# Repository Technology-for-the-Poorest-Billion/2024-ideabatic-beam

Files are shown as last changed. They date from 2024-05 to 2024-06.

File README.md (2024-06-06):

# SMILE, by Ideabatic
This is an IIA project, carried out in Easter term with the intention to improve upon the design of the current SMILE prototype.

# To Navigate Through this Repository

- The design considerations are linked coherently in a logic order, starting with a [formalisation of the design problem](https://github.com/Technology-for-the-Poorest-Billion/2024-ideabatic-beam/blob/main/Benjamin_Outputs/Our_Design_Problem_and_Context.md).

- The key information for mechanical design and prototyping can be found [here](https://github.com/Technology-for-the-Poorest-Billion/2024-ideabatic-beam/tree/main/mechanical%20design)

- The key information for electronic design and prototyping can be found [here](

## Setup (electronics)
In the final prototype, [the items listed here were used.](https://github.com/Technology-for-the-Poorest-Billion/2024-ideabatic-beam/blob/main/BillOfMaterials.md)

### Connections
The pi should be connected as [described here.](https://github.com/Technology-for-the-Poorest-Billion/2024-ideabatic-beam/blob/main/ElectricalConnections.md)
The connections can be switched around as long as they are appropriately changed in the code. The sensors initiate the pins in their own pieces of code, whereas the button, switch, and buzzer are initialised in main.py.

### Pi Setup
1. Install micropython onto the board. 
  - This can be done via thonny; connect the Pi to the computer whilst holding the BOOTSEL button, and install the standard relevant micropython.
2. Install the ssd1306 and dht libraries.
  - This can be also be done via thonny; with the pi connected and responding, click tools -> manage packages and install the libraries there.
3. Port over all items in the code folder.
4. The Pico, on boot, will run main.py by default. For testing, mainTest.py is recommended, as this changes the polling rate to 1 per second, and artificially inflates the heat loss so that the display stages can be shown. This also allows for testing of the buzzer.

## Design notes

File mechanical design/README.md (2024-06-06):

Author: Ness

### Handover notes

#### Prototyping insights
1. CAD design medium
2. 3D printing

#### Main design considerations
1. Snap-fit connection between module and door
2. Compatible joints between module base and lid
3. Drop resistance of electronics module
4. Dimensioning to fit components

#### Material selection (further discussed in Benjamin's part)

### CAD

#### Solidworks files
1. Door top 2024.SLDPRT [Part file with door top final design and suppressed 3D printed prototype iterations]
2. Module casing base 2024.SLDPRT [Part file with module casing base final design]
3. Module casing top 2024.SLDPRT [Part file with module casing lid final design]

#### OpenSCAD code [not used in final design]
1. door top modification.scad [OpenSCAD code of preliminary modifications to the door]
2. module casing.scad [OpenSCAD code of preliminary module casing design]
3. shell.scad [OpenSCAD code of assembled shell .STL components]

#### Other drawings
1. SMILE - shell only.STL [.STL export of the shell]

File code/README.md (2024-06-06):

### This folder contains the relevant code required to run the Pi. [For setup instructions, click here.](https://github.com/Technology-for-the-Poorest-Billion/2024-ideabatic-beam/tree/main)
# Logic Process:
1. The code imports all the functions, does so by importing the respective files. When importing test.py, the tests are carried out. If there is an issue, the terminal will let you know where the failure was. Switch/button failure is difficult to detect and so will have to be done in use. Buzzer testing can also be done but can be annoying if tested each time the code is ran.
2. Initialises all the extra electronics: the switch/button/buzzer so that it is ready to be used. Also imports the dictionary in constants.json with all the relevant values stored there.
3. Waits for the button to be pressed before starting the main loop. This is done by raising an interrupt on the rising edge of a button push (active low).
4. Once this is done, the push button is changed to the class SoftSwitch, which allows for debouncing and detection of double clicks, which on first click will revert the time remaining to the last measured time before boot up. Any further clicks will reset the cool life completely.
5. Now, the main loop of the code runs in a try: section. This ensures that if there are any errors that prevent the running of the code, the constants are dumped back to the JSON (important to remember the last known Q for later reversion), and the display is safely turned back off. 
6. The heat life calculations run first, where the heat loss rate is calculate using the temperature difference between the core and outside (T_outside - 0) and the (constant) thermal resistance of the cooler box. An estimation of the remaining cool life is made based on the assumption that the temperature remains constant, though this is updated every loop (of time period tdelta, default 5 minutes). If the remaining cool life is negative, the code will cause the buzzer to buzz for 2 seconds.
7. The remaining cool life is then displayed and the door switch is checked. If the door has been open for two consecutive checks, the switch will buzz every 5 minutes until it is shut. Note that the buzzer sound is irritating at worst.
9. The code then sleeps for tdelta, default 5 minutes before running the main loop again until power is cut.

# Issues and further improvements
- The battery life of the module can certainly be improved. When sleeping, the module sips 30mA at 3V which depletes 2 AA batteries in 78 hours, whilst the expected cool life at 22 degrees is just over 100 hours. 
  - The pico's power draw can be reduced by using machine.lightsleep instead of sleep, and additionally reducing the power draw of the display (i.e. by using a lower display brightness, using the display with a duty cycle).
    - Note that lightsleep may cut power to the display, and can have problems with the external modules. It is also incredibly annoying to prototype with, requiring a manual reconnect of the usb connector after each use.
    - If this is used, it may be beneficial to have the display only run when the button is pressed via an interrupt; this takes advantage of this aspect to further reduce the power consumption
- A relatively easy improvement to the code would be to have the display turn on for a second when the button is pressed once, before shutting off again, though this will make the module less useful; this was considered but decided against.
- A smaller on circuit temperature sensing component can be used (i.e. a TMP36) instead of the bulky DHT22 module currently used to improve the power draw, and allowing for more flexibility instead of relying on a library.
- The overall size of the module can be reduced by sourcing more use case specific components.
- A rechargeable battery can be used to provide the required lifetime, though this would require a battery management system too, along with a USB port which could reduce water resistance.
- A different microcontroller with even lower power draw may be preferable, possibly an ESP32, which has the added benefit of being very small.

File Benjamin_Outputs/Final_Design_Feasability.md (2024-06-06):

## Validating Analysis of the Final Design across all dimensions

### Modularity: 
- entirely electronically and mechanically modular for easy charging and opt-in 

### Robustness: 
- With the existing sealing not being compromised, water resistance remains
- With the [mechanical solutions implemented](https://github.com/Technology-for-the-Poorest-Billion/2024-ideabatic-beam/blob/main/mechanical%20design/handover%20notes/drop%20resistance.md), the final product is drop resistant

### Temeprature Prediction Veracity: 
- 1º overestimate proven to be sufficiently accurate



### Cost effectiveness: Validating Analysis
- Take the [worst-case quantity discounting for electronic components](https://github.com/Technology-for-the-Poorest-Billion/2024-ideabatic-beam/blob/main/Benjamin_Outputs/Initial_Design_Candidates.md)
- Add the single-unit cost of all materials used for housing, assuming no quantity discounting

Material costs:
- 0.9mm thick x 9080mm2 for [aluminium sheet](https://www.metals4u.co.uk/materials/aluminium/aluminium-sheet/aluminium-mill-finish-aluminium-sheet/3123-p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) for top of module casing
£0.22 for 0.01m2
- 30x14 of [2mm thick acrylic](https://www.perspexsheet.uk/clear-000-perspex/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) for screen display on top of module case: £0.02 per unit
- 13226.4mm3 of [ABS](https://www.plasticsdirect.co.uk/products/abs-sheet-acrylonitrile-butadiene-styrene), costs £1.37/kg; density is 1 g/cm3, so we are using 13.2264g, so material cost is £0.02; if we want it pre-processed, £0.31.
- two [PVC button covers](
https://undercontrol.co.uk/accessories/switches/pvc-splash-resistant-rocker-switch-cover/), £0.24 each

So only adds £1.03 to material costs.

<br />

Detailed research, including further input from the project partner to quantify the additional manufacturing costs is necessary for a complete analysis, but the original £15 in the [problem definition](https://github.com/Technology-for-the-Poorest-Billion/2024-ideabatic-beam/blob/main/Benjamin_Outputs/Our_Design_Problem_and_Context.md) was not expected to include manufacturing.

<br />

Hence, the final prototype is costed at £12.02 (electronics) + £1.03 = £13.05 in the worst case. So we remain under budget!

### Insulation: Validating Analysis

*This uses a different model: split the total thermal resistance of ABS into two parts: the insulation in door face and the insulation in all other faces. Then the thermal resistance in door face is reduced by a factor of (62-7)/55, which represents the percentage decrease in thickness; conservatively assuming that air in parallel with insulating material is as bad as just air in the top 7mm of the door*



Plugging the value for the total thermal resistance of the device into the cool life prediction algorithm, 



It is shown that the new device maintains 96% of the original cool lifetime, scoring an 8.98 on the insulation dimension according to its dimension characteristic.

<br />

### Conclusion

All five key dimension requirements are satisfied; a new KPI can be computed based on the slightly reduced insulation, at KPI/1000 = 27. Hence this still remains the best design candidate, and is proven to be a working prototype design. 

The next step is to build the actual product out of the recommended materials.

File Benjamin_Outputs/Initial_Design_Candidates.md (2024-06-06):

# The candidate designs

Based on previous work informing a ['default design'](https://github.com/Technology-for-the-Poorest-Billion/2024-ideabatic-beam/blob/main/Benjamin_Outputs/Our_Design_Problem_and_Context.md), four general candidate designs following this archetype were brainstormed, along with one outside of the archetype (Candidate 5):

IMG_548055A1CA77-1

<br />
<br />

Applying the [conservative principles for analysis](https://github.com/Technology-for-the-Poorest-Billion/2024-ideabatic-beam/blob/main/Benjamin_Outputs/Conservative_Analysis_Principles.md), each design was analysed via *eliminating analysis*, to result in a quantified measure of its best-case performance. Best-case performance was analysed at this stage to ensure that no viable designs were discarded. 

<br />

## Candidate 1: Direct Axial Connection - Eliminating Analysis on the Insulation Dimension



<br />
<br />

- This is the design prototyped by last year's group
- They neglected the obvious risk of insulation compromise

The first dimension on which Candidate 1 will be scored is insulation, in an attempt to elimiinate it early on the grounds that it compromises insulation to an unacceptable level. 

### The Problem:
- Electrical wiring, made of copper, is very thermally conductive, so an axial path of heat flow is effectively short-circuited.
- Additionally, there is a manufturing and design interdependence. Given that the door is intended to be manufactured by polymer casting, there is significant tolerance. 
- To ensure that the wires fit in the door, the design therefore needs to made too wide. Then with the tolerance, the best case still results in some parts in the manufacturing batch containing a significant air gap around the wires. 

Inkeeping with the conservative analysis principles, the analysis will be done with the following assumptions, each of which leads to the most conservative estimate of insulation compromise:
- the wiring used is has the lowest readily available diameter, 1 mm
- manufacturing is done with maximal precision. For casting a polymer, this is of order ±1 mm accuracy on casting

- the change in area of the door cross-section is neglected

### Optimising Geometry: 
Coordinate geometry reveals that the optimal housing for wiring is 'figure 8' shaped.
Evaluating the area of the lens shape created by the two tunnels overlapping, this results in: 1.57mm<sup>2</sup> wiring, 3.83mm<sup>2</sup> air.

IMG_BBFAF02D5158-1

The bulk of the door is made of the insulating material tricast. 
Previous contributors computed the average thermal resistance *per unit depth* of door to be 

$\ {R_{th, tri}} =$ = 198.6 KW<sup>-1</sup>m<sup>-1</sup>

The area of copper in two 1mm diameter copper wires is 1.57 mm<sup>2</sup>, 

$\implies$ *per unit depth*,

$\ {R_{th, copper}} =\frac{1}{\lambda\times{A}} =\frac{1}{{398}\times{1.57\times{10^-6}}} =$ 1600 KW<sup>-1</sup>m<sup>-1</sup>

$\ {R_{th, air}} =\frac{1}{\lambda\times{A}} =\frac{1}{{0.025}\times{3.83\times{10^-6}}} =$ 10.4 x 10<sup>6</sup> KW<sup>-1</sup>m<sup>-1</sup>

The three resistive elements are in parallel through the entire depth of the door, so 

*modelling these as a thermal resistances in parallel with the insulating material tricast*,

$\frac{1}{R_{th, total}} = \frac{1}{R_{th, copper}} + \frac{1}{R_{th, air}} + \frac{1}{R_{th, tri}}$

$\implies {R_{th, total}} =$ 176.7 KW<sup>-1</sup>m<sup>-1</sup>

Thus the thermal insulation of the door per-unit depth is reduced by 11.04%. 

Using data from previous contributors to compute the new total thermal resistance between the ice pack at the centre of the cooling device and the external air, the thermal resistance is found to be reduced from 9.72 to 8.88 KW<sup>-1

The new value for overall thermal reistance was simulated in the cool life estimation algorithm, and the effect of the axial connection was plotted:



Cool life decreases from 97.5 hours to 89.1 hours in 24ºC ambient temperature. 

This is deemed feasible - the reduction in cool lifetime is not drastic enough to eliminate this candidate entirely. 

However, it will be scored lower than the other design candidates, which don't threaten any significant reduction in insulation. 

According to the scoring characteristic, this design therefore receives a score of 7.6 on the insulation dimension. 

## Candidate 2: Wireless Communication - Eliminating Analysis on the Cost Effectiveness Dimensions

The dimension on which this design is most liekly to be unfeasible is cost effectiveness. 

According to conservative analysis principles, the best-case possibility is explored: 
- the lowest-cost implementation is used, which is to use a second microcontroller which can wirelessly communicate with the Pi Pico
- the quantity discounts for bulk-ordering is assumed to follow the best-case exponential decay per-unit cost curve derived below

### The electrical components needed

- Pi Pico → Pi Pico W to allow for wireless communication

- Wireless module microcontroller (ESP8266) to operate temeprature sensor and communicate with Pi Pico

- AA batteries x2 needed to power ESP8266

- Holder for AA batteries

### Deriving Possible Quantity Discount Curves
- Most electrical component websites offered limited information on the discounts offered for ordering components in large quantites:



#### Table 1: Example of publicly avaialble quantity discounting data

- Via private communication with suppliers about buk orders, a more detailed range of possible quantity discounting curves were obtained.
- The discounting data received only extends to 1000 units at most, whereas our batch size was 3000
- By modelling the quantity discounts a logarithmic decay, the range of cost curves were extrapolated to a batch size of 3000 to obtain a best-case and worst-case estimate for the quantity discount offered on electrical components. 
 




- For a best-case eliminating analysis, the most generous discounting rate across websites and components was assumed 

****Best-case Per-unit price for 3000 units = 0.5 x Per-unit price for 1 unit****

This is the best-case estimate which is used for the cost-effectiveness feasability assessment of Design Candidate 2. 

### Best-case cost effectiveness of Candidate 2

| Part Description | Single Unit Cost | Per-Unit Cost in batch of 3000 | 
|-|-|-|
|Raspberry Pi Pico W| £5.80 | £2.90 | 
|ESP8266| £4.22 | £2.11 | 
|DHT22| £4.74 | £2.37 | 
| OLED Display | £10.19 | £5.10 | 
| Door-sensing switch | £1.02 | £0.51 |
|Buzzer for door open alert| £2.15 | £1.08 | 
|Battery holder x2 | £1.96 | £0.98 | 
|AA Batteries x4 | £2.316 | £1.16 | 

The cost of electrical wiring, resistors and capacitors is neglected. 

#### Best-case per-unit cost for 3000 units: £16.20

This is above the budget (even before considering the cost of the housing for the module), making the cost effectiveness score zero, giving Candidate 2 a KPI of zero. 

Candidate 2 will therefore be eliminated from consideration without further consideration. 

The other design candidates' electronic components are costed at £24.03 for a single unit, which is a per-unit cost of £14.42 in the worst-case quantity discount, and £12.02 in the best case, thus they are all within budget and receive score of 5. 

<br />

## Scoring all candidates on all dimension

Scoring each design on according to the [scoring criteria](https://github.com/Technology-for-the-Poorest-Billion/2024-ideabatic-beam/blob/main/Benjamin_Outputs/Design_Approach.md), the following table was constructed, representing the overall performance. Candidate 2 was not scored as it was proven inviable on the insulation dimension. 

<br />

| Dimension | Candidate 1 Score | Candidate 2 Score | Candidate 3 Score | Candidate 4 Score | Candidate 5 Score | 
|-|-|-|-|-|-|
| Cost effectiveness | 5 | 0 | 5 | 5 |5 | 
| Robustness | 5 | - | 8 | 8 |10 | 
| Insulation | 7.6 | - | 10 | 10 |10 | 
| Temp Prediction Veracity | 10 | - | 10 | 10 |6 | 
| Modularity | 6 | - | 6 | 6 |10 | 
| **Overall KPI /1000** | **11.4** | - | **24** | **24** | **30** |

<br />







Hence, the design taken forward is candidate 5, with a specific focus on improving/validating its performance in the 'temperature prediction veracity' dimension, and ensuring that its cost effectiveness, robustness, insulation and modularity are upheld, as it is selected for its good performance across these dimensions. 

<br />
<br />

The specifics of how this design could be implemented, particularly its [door sensing mechanism](https://github.com/Technology-for-the-Poorest-Billion/2024-ideabatic-beam/blob/main/Benjamin_Outputs/Module_Placement.md) and the placement of the [temperature sensor](https://github.com/Technology-for-the-Poorest-Billion/2024-ideabatic-beam/blob/main/Benjamin_Outputs/Internal_DHT_Analysis.md) were then analysed.

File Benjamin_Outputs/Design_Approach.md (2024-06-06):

# Communicating Design Decisions

Part of this project's useful output is a thorough documentation and justification of all design decisions made, quantified and visualised where possible. 

This is useful in the immediate term, as a means of presenting and justifying design decisions to the project partner, and also in the future, as subsequent work on this design problem will be streamlined by the clarity of this discussion, illustrating possibilities that have already been explored and eliminated. 

<br />

The [formalised problem definition](https://github.com/Technology-for-the-Poorest-Billion/2024-ideabatic-beam/blob/main/Benjamin_Outputs/Our_Design_Problem_and_Context.md) naturally gives rise to five key dimensions:
- Cost effectiveness
- Robustness: Environmental resistance and mechanical robustness
- Insulation
- Veracity of temperature prediction
- User friendliness, primarily concerned with modularity

<br />

Each possible design (known hereon as a design candidate) should perform well in all five dimensions. 

It will be scored against each dimension, using the scoring criteria outlined below.

<br />

# Scoring Candidates on Each Dimension

## Scoring Criteria

Based on personal judgement and continual discussion with the project partner, the following subjective (yet defensible) criteria were used for scoring on the five dimensions. 

These criteria can be thought of as a way of taking the physical performance dimension (eg cool lifetime) and mapping it to performance in a dimension (eg insulation). 

### Cost effectiveness
- Any design which is unfeasible within the £15 budget is scored zero
- The remaining four designs are inseparable on cost (neglecting cost of wiring), so are all scored 5
- This is a rudimentary scoring characteristic, but given that we only have two possibilities for costing (given that four of our designs have exactly the same cost), it is sufficient

### Robustness: Environmental resistance and mechanical robustness
The primary risks for environmental and mechanical degradation are water ingress and damage to external wiring.
- Any design which might be susceptible to water ingress is scored 5
- Any design which requires external wiring is scored 8 (can be mitigated by further printing wiring)
- Any design with both of the above is scored 4
- Any design with neither is scored 10

### Insulation
- Any design which does not compromise insulation is scored 10
- Any design which multiplies the 24º cool lifetime by a factor k is scored k<sup>3</sup> x 10
- The cubic scoring characteristic gives severe weighting to the cool lifetime of the final product, which is appropariate since improving cool lifetime is the SMILE's core function

### Veracity of temperature prediction
- Any design with the temperature sensor outside the insulation is scored 9 (an extra layer between sensor and vaccines increases error in algorithm, as there is uncertainty associated with the exact thermal resistance of each layer)
- Any design with the temperature sensor susceptible to mild inorganic heating (eg due to contact with the electronics) by less than 1ºC is scored 7
- Any design with both of the above is scored 6
- Other designs are scored 10
- Only small scoring penalties are applied here as underestimates of the cool lifetime are not costly - whereas overestimating cool lifetimes could cost lives!

### User friendliness, primarily concerned with modularity
- Any design which has both mechanical and electrical modularity is scored 10
- Any design which is mechanically but not electrically modular is scored 6
- This is based on the preferences of the project partner in designing two versions of the product with one manufacturing process, so that users can easily opt in or out of the electronic version

<br />

Once scored against each dimension, a design candidate's performance can be visualised using a radar plot.



****Figure 1: Example of a radar plot****

The scores will then be combined to give a Key Performance Indicator (KPI), which quantifies the overall performance potential of a design. 

Given that a failure to be fit for purpose in any of the five dimensions would render a design unsuitable, the KPI is calculated as the product of the five scores.

$\{KPI}$ = Score 1 $\times$ Score 2 $\times$ Score 3 $\times$ Score 4 $\times$ Score 5

This product-rating method is also useful for eliminating design candidates: evidence that a candidate is unsuitable on any of the five dimensions immediately sets its KPI to zero and eliminates it from the design process. 

As such, each candidate is checked first against its most problematic dimension in a 'feasability test', so that it can be quickly eliminated if unfeasible. 

The radar plot conveniently visualises three important things:
- Area shows which design candidates to proceed with
- Relative strengths and weaknesses of each design candidate
- Areas for maximum improvement on each design candidate

[This document](https://github.com/Technology-for-the-Poorest-Billion/2024-ideabatic-beam/blob/main/Benjamin_Outputs/Initial_Design_Candidates.md) shows the general candidate designs which resulted from brainstorming, and the feasability assessments and dimension scoring which resulted in the prototyped design being taken forward.

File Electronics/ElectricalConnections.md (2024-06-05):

# Electrical connections to Pi Pico
Note that the below makes reference to the board pins and GPIO pins. See pico.pinout.xyz for more information.

## Pinout:
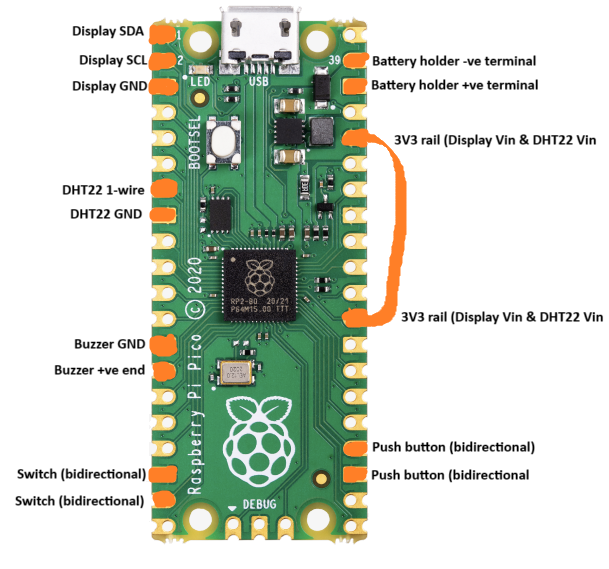
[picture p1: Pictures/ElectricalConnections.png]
Electrical Connections


|Board|GPIO/V|Purpose|
|-|-|-|
|1|GP0|Display SDA|
|2|GP1|Display SCL|
|3|GND|Display GND |
|7|GP5|DHT22 1 wire |
|8|GND|DHT22 GND|
|13|GND|Buzzer GND|
|14|GP10|Buzzer Positive end|
|18|GND|Switch (bidirectional)|
|19|GP14|Switch (bidirectional)|
|23|GND|Push button (bidirectional)|
|24|GP18|Push button (bidirectional)|
|29|GP22|Connected to board 36(3V3 Out). Used as an extended positive terminal for further wires. (Display Vin and DHT Vin are connected to this)|
|36|3V3 Out|Connected to board 29 (GP22). Used as an extended positive terminal for further wires. (Display Vin and DHT22 Vin are connected to this)|
|38|GND|Battery holder positive terminal|
|39|VSYS|Battery holder positive terminal|

<!--
<BR>Board 1 (GP0): Display SDA
<br>Board 2 (GP1): Display SCL
<br>Board 3 (GND): Display GND 
<br>Board 7 (GP5): DHT22 1 wire 
<br>Board 8 (GND): DHT22 GND
<br>Board 13 (GND): Buzzer GND
<br>Board 14 (GP10): Buzzer Positive end
<br>Board 18 (GND): Switch (bidirectional)
<br>Board 19 (GP14): Switch (bidirectional)
<br>Board 23 (GND): Push button (bidirectional)
<br>Board 24 (GP18): Push button (bidirectional)
<br>Board 29 (GP22): Connected to 3V3. Used as an extended positive terminal for further wires. (Display Vin and DHT Vin are connected to this)
<br>Board 36 (3V3 Out): Connected to board 29 (GP22). Used as an extended positive terminal for further wires. (Display Vin and DHT22 Vin are connected to this)
<br>Board 38 (GND): Battery holder positive terminal
<br>Board 39 (VSYS): Battery holder positive terminal -->

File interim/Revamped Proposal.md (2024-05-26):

# Problem description

<!-- Brief overview of the problem, context and engineering approach to tackle the problem.-->

Current vaccine carriers use cooler boxes which are poorly adapted to the conditions that they are expected to tackle, often with very poor cooling lifetimes that can mean vaccines spoil before they reaches their destination. These were shown to last approximately 4 hours in field conditions, which is simply not enough for journeys that can often last 2 days in over 25ºC heat. Human error is also a large problem, as healthcare workers may unknowingly leave cooler boxes open for long periods of time, significantly reducing the cooling lifetime. There is also an issue in which, despite requiring four standard ice packs placed appropriately, workers may end up only using one or two, placed haphazardly. 

SMILE, by Ideabatic, aims to combat this issue with a uniquely designed cooler box containing only a single ice pack that can keep 18 vaccines cool for up to 4 days (120 hours), along with a self-closing door mechanism to reduce human error. The design also incorporates a waterproof casing with further insulation and straps for comfortable carry as a backpack. Clearly responding to a genuine need, the impact of SMILE can be assessed against UN's sustainable development goals, most obviously Goal 3: Good Health and Wellbeing. 

<!-- Contextualising the project, embracing last years work and being explicit about improvements we intend ot make-->

Ideabatic has been collaborating with many different project groups to develop a temperature display electronics module as an add-on product to the SMILE device. The need for such a product was identified after some users relayed that they wanted to keep track of the temperature in the SMILE device to better ensure the vaccine is stored properly.

Previous project groups have worked on different electronics housing and door slot designs, developing temperature and cool life prediction algorithms and door alert systems, and improving other mechanical features such as the self-closing mechanism and lid ergonomics. This project aims to build upon the work done by these previous groups, identifying the limitations of previous designs and improving on these features based on feedback given by Kitty Liao (founder of SMILE) and personal insight.

# Assessment of the quality of the proposal

<!--Evaluate its value in the context of the project. What will it solve, is it safe, etc. Check Lara’s slides for what to cover.-->

The SMILE coolbox works as it is, and is safe for users. Despite this, it has come up against approval and funding issues. Ideabatic has decided to take the device to developed markets (such as the UK) as a proof of concept, along with the addition of further features which can be included or removed as costs require for developing market applications. 

There are three core improvements to the existing design that we are looking to implement:

The door being self-closing, and/or warning users if left open, has been proven by field tests to be a functional necessity. Due to carelessness, the door is often left open, which leads to unnecessary spoiling of the vaccines. Ergonomics of the door opeartion is essential for ease of use, and must accommodate the varied nature of applications and shapes and sizes of users. 

Implementing a simple display, showing the cool life remaining, or at its simplest, an 'OK' or 'NOT OK' signal, is a high-impact safety feature, which allows the administer of vaccines to be aware when vaccines have spoiled, and when they need to return to restock the icepack. Here, information saves lives. 

The current algorithm for estimating the temperature in each vaccine compartment has been calibrated assuming that the SMILE door is closed at all times. In reality, the door will frequently be opened, especically during an administration session. This leads to much faster cooling rates (extent to be determined), and thus shorter cool lifetimes. To obtain an accurate temperature estimate and make the display worthwhile, the algorithm should thus be improved to include the effect of the open door; preferably coupled with a real-time sensor on the door to indicate its state. 

# Presentation of the proposal

<!--Technical aspects may be described here--> 

## Electronics
The main electronic priority is to implementing a functioning, modular and accurate temperature sensing display. The team last year did this through an Arduino, though our group is looking to use a Raspberry Pi Pico. The hope is to have a user-friendly interface that will display whether the vaccines are within the safe temperature range and, upon further interaction, how many hours the vaccines stored inside will likely last under the current temperature conditions. There is also the possibility of adding a GPS sensor to locate the cooler and then log this, along with the temperature sensing data, in a storage device that can later be accessed. This should all be incorporated in a module which can be removed and fit as desired, leading to some intricacies within the actual door design. This module will contain a temperature sensor, measuring the ambient temperature, and there will also be a static temperature sensor embedded inside the door. The module will then be able to interact with this sensor when attached to the door. 

Another priority, albeit lower, is the improvement of the temperature sensing algorithm. The current function works by calculating the heat energy lost to the surroundings (treating the thermal resistance and total ice pack energy as constants) and decrementing the cool life accordingly. It does not currently consider how the door opening will affect the remaining cool life which is something that we are looking to add. The team last year has also worked on a system that detects when the door is left open and beeps after a given time. This currently works off of a simple button switch, with some different designs explored, though ultimately more testing needs to be done to figure out how well it worked, or if there are different methods we need to look at.

## Mechanical
The mechanical component involves designing a compatible “snap-fit” electronics module housing and door slot design, as well as improving on previous iterations of the ergonomics and robustness of the self-closing door mechanism.

OpenSCAD would ideally be used for the individual designs of the electronics module housing, door slot, internal placement of sensors, and spring mechanism. 3D printing would then be used to test and redesign components iteratively. User experience design could be used to assess the effectiveness of the design in achieving ergonomics and use preferences. Some important features to be included in the improved design is resistance to damage in case of dropping, as well as containing minimal parts for easy manufacturing. The thickness of the electronics module and casing is also important to consider such that insulation thickness at the door is not significantly affected. Stress and life cycle analysis of the torsional spring may be investigated to check robustness. Additional aspects such as waterproofing may be explored. The outcome should be a modular, integrated electronics casing and door system with improved ergonomics and mechanism robustness.

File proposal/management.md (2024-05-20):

# Project management plan

## The people
<!-- Team members strengths and weaknesses.
Skills required, training needed.-->

### Romeo
Have experience prototyping electronics with a Pi 4 and different sensors, with understanding of different communication protocols used, and have used tkinter within python to make a very simple display on an LCD. Have experience with 3-D printing, having done so both in department and at home. 
<br> Requires training, or examples given, for C++ code, and for building a display interface.

### Benjamin
Some experience with implementing a sensor module on a Raspberry Pi Pico. Probably well suited to exploring the temperature algorithm improvement problem (accounting for the opening of the door). 
<br> Good communicator, suited to taking on task management, timeline and operations tasks.
Unfamiliar with CAD. 

### Ness
Experience using CAD for extracurricular projects. Training needed on specific rapid prototyping skills such as OpenSCAD and 3D printing.

## The resources needed
<!--Costing, parts required.-->
| Part Description | Quantity| Unit Cost | Link |
|-|-|-|-|
|Rechargable| 1 | ~ £20 | To be sourced - if outside budget, revert to AAs or powerbank |
|Connectors for module| 1 | £5.53 | https://uk.farnell.com/hellermanntyton/148-90056/wire-splice-terminal-pc-10pcs/dp/3255511 |
| Temperature sensor | 2 | £6.83 | https://uk.farnell.com/dfrobot/sen0137/dht22-temp-humidity-sensor-arduino/dp/3517874?ost=3517874 | 
| OLED Display | 1 | £14.04 | https://uk.farnell.com/seeed-studio/101020452/oled-display-1-12-128-x-128-pixels/dp/4007703?ost=4007703 | 
| Raspbery Pi Pico H | 1 | £4.73 |  https://uk.farnell.com/raspberry-pi/raspberry-pi-pico-h/raspberry-pi-board-arm-cortex/dp/3996081| 
| Solderless Breadboard | 2 | £3.38 | https://uk.farnell.com/multicomp/mcbb400/breadboard-solderless-300v-abs/dp/2395961 | 
| Buzzer | 1 | £3.26 | https://uk.farnell.com/projects-unlimited/ai-3245-tf-lw95-r/audible-signal/dp/1653528 | 
| Wires | 1 | £3.32 | https://uk.farnell.com/multicomp-pro/mp006282/jumper-wire-kit-male-to-male-100mm/dp/3617770?st=jumper%20wire | 
| Switches / Buttons | 1 | £1.98 | https://uk.farnell.com/omron-electronic-components/d2ffl/microswitch-hinge-lever-1a-pcb/dp/1961095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 | 
| 3D Printed Parts | Unknown | £5 | N/A | 
| AA battery module | Unknown | £5 | N/A |

Note that these are rough estimate for the  parts needed; more research is needed to look into some of these parts to find more fitting alternatives.

## The timeline
<!--NEED TO MAKE ROUGH TIMELINE-->
Timeline can be found here.

## The assessment of the risks and safety

| Potential Hazard | Risk Level | Hazard Control Strategies |
|-|-|-|
| Excessive exposure to VOCs and <br> ultrafine particles from 3D printer| Medium | Proper ventilation <br> Check material is safe to use <br> Turn off printer if jammed|
| Burning oneself with soldering iron | Medium | Take care when using soldering iron, exhibit appropriate precautions |
| Burns from hot surfaces on printer | Medium | Wear protective gloves <br> Don't touch extruder or molten plastic <br> Check bed temperature before handling printed item|
| Getting trapped by moving parts <br> in 3D printer | Low | Keep clear of all moving parts|

## Contingency plans
<!--What could go wrong? What to do when it happens?-->

### Electronics

#### Inability to find sufficient connectors to attach the module with the required strength
If connectors for modular electronics are mechanically unstable, the team can instead look towards a simpler plug and play approach with dupont connector wires for simplicity sake, magnets can also be incorporated. 

#### Module unable to be compressed well enough whilst still allowing optimal functionality
To implement the desired features, the electronics module may become too large to be clipped as a modular unit to the door. In this case, the design can be reverted to include all components within the door, whilst having the door be modular. This effectively solves the issue of keeping the electronics modular, though isn't as feasible to do.

#### Failure to rebuild code for Pi Pico
The decision to switch to a Pi Pico has been done as the Pi Pico is a lot cheaper than an Arduino nano (and thus a lot more befitting of the project), and for familiarity with the team. If converting the available code to work with the pico takes too long, it may be a better idea to switch back to the Arduino, as the code has already been proven to work. 

#### Failure to add GPS tracking, or data logging
These are effectively "nice to haves" and aren't primary objectives. Most likely barrier to implementing GPS is cost. Most likely barrier to implementing data logging is that the spatial requirement for an SD card could make the module too large to be modular. 

#### Difficulty in adapting the temeprature algorithm to account for door open
This was suggested by Kitty to be too diffuclt to take on in three weeks. The previous team's algorithm still worked sufficiently well, so if she turns out to be correct, we can resort back to their algorithm and focus our efforts on the other aspects of the task.

#### Budget Constraints
If certain parts (eg rechargable battery) are too expensive, revert to less expensive alternative (eg AAs or power bank)

### Mechanical

#### 3D printing takes a long time, during which changes may have already been made to the design

For large components like the door, 3D print smaller segments of the design for testing so that faster iterations or comparisons could be made. Before each print job, ensure all changes to the design have been included, and that they are necessary to the design.

#### OpenSCAD may be too difficult to pick up

CAD Solidworks could be a fall back option since it is more familiar. Previous group also used Solidworks and so there are more reference files to build from.

#### Failure to design "snap-fit" module and door
The snap fit mechanism needs to be decided on rather early in the design process to ensure compatibility between different parts. If such a mechanism could not be reliably prototyped or functional, it would cause difficulties in continuing with other aspects of the project. Therefore it should be the first point of investigation before deciding on other aspects of design.

#### Difficulties integrating electronics with casing design
As the casing design is dependent on the type and number of components used by the electronics team, later changes to the design of electronics may affect the design of the casing. If it takes a long time to settle on a design for the electronics module, there may not be enough time to complete the casing design. Ensure the dimensions of slot and casing prototypes can be easily changed in later iterations to accomodate changes in size of the module, and work with electronics team to ensure shape of module is reasonable.

#### No time for improving robustness of spring mechanism
It is foreseeable that we may run out of time to deeply investigate the self-closing door mechanism, as it involves improving on many iterations of previous designs that may have explored most aspects of torsional springs, and may require extensive testing to yield new results. It is not the most critical aspect of this design iteration.

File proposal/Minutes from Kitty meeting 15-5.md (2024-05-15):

# Romeo's minutes
-	Focus on making sure the temperature sensing function works really well.
-	Electronics: simple, easy to understand and reliable. Focus on simplicity: for screen simply display: OK or NOT OK, then upon further click display the remaining cool life in hours?
-	Freedom to choose what is included in the actual display.
-	Worth surveying people: blind trialling?
-	Once the above is done well, then detect if the door is open and adjust algorithm accordingly.
-	Focus on the user side, ease of access and simplicity.
-	Modular electronics, within its own casing to clip onto the door element, instead of having separate elements -- difficult installation to be avoided.
-	Idea is to have the battery easily removed (presumably along with the screen for charging?
-	GPS and data logging are more of a nice to have but probably relatively easy to implement.
-	Rechargeable batteries are preferred over standard replaceable batteries.
-	When designing handles, avoid deeper that will occupy space that could have been used for insulation.
-	Smaller LCD preferred over larger – can look towards which size might be ideal for getting across the information. Look into how necessary buttons are.
-	Wider and thinner designs preferred over deeper (again for insulation)
-	Waterproofing nice to have but prioritise design.
-	Make current handle less wide? Look into more prototyping.
-	Documentation should have more information on how you got to the final design – this holds important information for future designers – especially why things didn’t quite work. Might be good to have backups of the prior iterative designs.
-	Think about drops – how might we protect the screen? Slightly deeper than surrounding area.
-	Think about the modularity – how easy is this to do. Clips to have the “screen module” attach to the door? Ideally have the battery and screen/sensor/microcontroller etc all in one module that then attaches, research required to look into best way of implementing this – using magnets instead of clips would be interesting, but depending on mass of module may not be powerful enough.
-	Outside sensor mainly used for remaining cool life, inner for backup/monitoring (?)
-	Private GitHub preferred, WhatsApp questions – maybe even make a shared drive to share things?
-	20C probably best for testing/modelling: https://drive.google.com/drive/folders/15KfUTUK4o-9_mfXlAF1HeKQmgM5Zm7Bo & https://drive.google.com/drive/folders/13nn9-MJRJQJbd6YWNrIXZLQqjzbAK4W1 

# Ness's minutes
wrt CASING:
- electronics module casing, modular, click-on mechanism onto door design
- removable from the top for charging, without disturbing temperature sensor
- more spread out design of casing rather than deep so insulation thickness is not as affected
- depends on electronics components
- waterproofing not the most important but could consider

wrt DOOR:
- could reference previous year designs of self closing door (20C)
- advice: print and test and iterate hardware
- in final report, show how you got to a final design and describe why other designs are problematic in trials 
- investigate torsion springs and other aspects of door, especially ergonomics for finger grip
- a hole in the top for module, should not go over the door top plane, to prevent damage in case of dropping
- minimal parts, want top to be planar with the frame of the chamber
- modular door so that electronics module could be installed

integration wth ELECTRONICS:
- in case of jams, signal or alert to users?
- temperature sensor with a connector with pins (like a charging port), and an electronics module with a matching connector
- find quality off the shelf connectors, but consider strength of spring for self closing design

# Benjamin's minutes
- Kitty thinks that modelling the temperature evolution with door open would be very useful but potentially too difficult, maybe we could make a start regardless? Could easily adapt model using datalogger and parameter tuning. 
- Kitty prefers final output of project to be shared via Google Drive rather than Github

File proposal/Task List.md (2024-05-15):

## Electronics/Software:

- Primary target is accuracy/functionality and ease of use!:

  Initial display only shows OK or NOT OK; maybe time remaining. Press button for exact temperature, further features like GPS

- Datalogging of temperature, sotred in micro SD card that is easily removable

- Implement a sensor for when the door is open or closed; and an indicator to alert if door left open (beeping)

- Make a start on making temperature predictor compatible with door opening; informed by existing data

- Charging mechanism needs to be compatible with modular nature of electronics module: sensor is fixed in door but won't be removed, 
  the rest of the module is removed for charging (clip on, clip off)

- Probably using rechargable batteries

- Need electronics module to be as thin as possible 

## Mechanical:

- Design of electronics module housing, needs to be modular (an optional add-on to the overall device)

- Design of door for integration with electronics casing

- Design for installment of modular circuitry (with temperature sensor)

- Improve self-closing door mechanism, especially ergonomics

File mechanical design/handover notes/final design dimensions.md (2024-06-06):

## Dimension determination proccess



### Initial dimension considerations

Mod bottom iso

BATTERY (tallest component)
battery casing height 15.45 mm
battery holes spacing 15.00 mm
battery holes diameter 3.30 mm

SWITCH (protruding component)
switch body 12.7 mm
switch button 14.51 mm
switch hole max distance 8.63 mm
switch hole min distance 4.50 mm

Consideration: 
Cavity in door top surface must be 15.45 - 12.87 mm = 2.7 mm deep at least.
We want it deep enough for stability of snap-fit mechanism, so choose higher value of 7 mm.



This gives initial internal module casing dimensions of:
Long height = 21.6 mm
Short height = 14.6 mm



Consideration:
Shells should be multiples of 0.8 mm (2 nozzles thick) for 3D printing.
Case cover and case base should form the combined module height.

Exploded

Therefore:
Case cover of height 3 mm
Case base of (short height) 11.6 mm

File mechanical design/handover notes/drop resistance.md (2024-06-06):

## Drop resistance

Two main designs to consider.

### Hemispheres in four corners

Fall damage 1

Advantages:
1. Symmetrical design.

Limitations:
1. If dropped at a shallower angle, the module is still impacted.
2. The radius of curvature of the lid edge is 14 mm, but module extends above lid by 14.8 mm. Therefore, the hemispheres cannot be exactly at the corners of the lid, or cannot be exact hemispheres. However, the later increases the slenderness of the protruding hemispheres which decreases strength and increases the change of snapping.

### Soft ridge around module

Fall damage 2

Advantages:
1. Guarantees protection of module.

Limitations:
1. Asymmetrical design may cause further imbalance of force distribution on the torsional spring when opening or closing the door.
2. More material needed than for hemispheres.
3. Very irregular surface that is not very functional or aesthetically pleasing without the presence of the module, a big loss for users that did not opt-in for the module.
4. Takes up more space, may need bigger bag for storage.



Ended up choosing soft ridge due to better protection of module, but further brainstorming is neccessary.

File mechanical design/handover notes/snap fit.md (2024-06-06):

### Snap fit mechanism



Problems with conventional snap-fit mechanisms:
1. Incompatible with 3D printing techniques because of deformation causing large tension in anisotropic 3D printed grain (layer separation is much easier than across layers).
2. Difficult mechanism to remove module after snapping in. Requires the presence of holes in the module, making it not watertight.

### Socket design

Inspired by the original design idea of using the electrical connector between the elecronics module and the temperature sensor module as the main connecting mechanism.

Based on plug socket designs. Pins are arranged such that module orientation is easily determined.

Ass (2)
Mod bottom connector
Door iso

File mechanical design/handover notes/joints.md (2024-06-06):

### Joints

#### Iteration 1

Mod 1 top

Mod 1

There were problems in interfacing due to 3D printing not producing perfect round surfaces.
Joints were too slender and snap off.



#### Iteration 2

New design direction: 1) square joints. 2) less slender joints.

Mod bottom iso

Much better interfacing. Less slender joints also meant the connecting shear force is less strong, but this can be supplemented with plastic welding to ensure watertight finish in final product.




Module lid component needs to be made out of Aluminium for heat conductivity, so placing the holes in the lid is more compatible with metal manufacture techniques like hole punching.

Mod top plane

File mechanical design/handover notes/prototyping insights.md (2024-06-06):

## Prototyping insights

### 1. CAD design medium

The project was originally planned to be done on OpenSCAD due to the following advantages:
1. Modular programme code
2. Increase accessibility for future design modifications by project groups


Figure: Assembled OpenSCAD model of SMILE shell.

However, I faced different limitations:
1. [Most important] Original SMILE design files were on Solidwork, compatibility issues as imported .STL files cannot be modified
2. Not able to directly orient or locate .STL files in OpenSCAD
3. Difficult to assemble components, need to constantly refer back to original Solidworks file
4. Axes are sparse and imprecise, no grid visualisation
5. [Less important] Not as visually intuitive as Solidworks, required time to get used to

As the limitations outweight the advantages, this led me to not pursue OpenSCAD as the final design medium. The designs were done using Solidworks.

### 2. 3D printing

List of problems faced using RS 3D printers:
1. Poor tolerance, components do not fit together well
2. Rounded surfaces do not print well
3. Supports require a lot of manual effort and time to remove, hinders rapid prototyping
4. Imperfect removal of supports cause problems in joining interfaces

Higher quality printers (Ultimaker) were occupied by other groups, prioritise using those printers if future project groups are to prototype. Benefits include:
1. No raft support. Raft supports were the most difficult to remove.



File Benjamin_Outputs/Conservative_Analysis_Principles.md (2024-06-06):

Each analysis checks the design against one of the five dimensions.
Each analysis is either eliminating (attempts to discard a candidate design) or validating (attempts to justify a candidate design being pursued)

## Eliminating analysis: 
Uses only the most generous assumptions and over-estimates performance (Best-case)

<br />
<br />

## Validating analysis: 
Uses only the harshest assumptions and under-estimates performance (Worst-case)

<br />
<br />

By adhering to the conservative analysis principles, we ensure that:

- **No viable designs eliminated** 
- **No inviable designs are finalised**

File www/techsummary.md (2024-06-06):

---
title: Technical Summary
---

## Modularise the electronics. Minimise the compromise to insulation.

As the electronics module is an additional opt-in product, we must ensure the design must still be watertight and properly insulated without the electronics module. Five key performance indicators (cost effectiveness, robustness, insulation, veracity of temperature prediction and modularity) were used to rank design candidates and determine our project direction.



One significant feature of our final design is having only one singular module that contains all of the electronics components, which diverges from previous designs which had another separate module for the temperature sensor.

Rapid prototyping techniques like CAD modelling and 3D printing were used to test various aspects of design, such as joint interfacing. Careful consideration was also taken to choose quality electronics and materials for the final product within our target budget.




## Electronics module
Within the electronics module, all the electrical componens are housed with a focus towards maintaining water resistance. 
In use, the final prototype works great, with the one drawback being the battery life.

### Main function
In its final state, the prototype was able to calculate the remaining cool life of the vaccines, and display this on the screen. It allowed for user interaction via button presses, allowing the user to revert to the last known Q (if the battery died), and upon further double clicks, reset the cool life time (if the ice pack was replaced). The door switch was implemented such that if the door was left open, within 10 minutes the buzzer would activate temporarily, allowing the user to close the lid.

### Specific details

The list of components used in the final prototype can be found below, with the appropriate soldering carried out:
- Pi Pico 
- OLED display
- DHT22 temperature sensor
- Buzzer
- Push button
- Button switch
- Battery holder (for two AA batteries)

A simplified logic process behind the code is described below. [For more details, click here](https://github.com/Technology-for-the-Poorest-Billion/2024-ideabatic-beam/tree/main/code)
1. Initialises components, like the temperature sensor and display, making sure these are connected properly.
2. Prompts the user via the display to press the button to then commence calculating the remaining cool lifetime.
3. Main loop runs, calculating and displaying the remaining cool lifetime with appropriate warnings displayed once theres a certain cool lifetime left.
4. The door switch is then checked, and if it has been open for more than 2 consecutive times (ie if the door has been detected as being open in two runs of the main loop), it will buzz the buzzer.
5. Main loop sleeps for 5 minutes before repeating steps 3 onwards until the battery dies.

Authors: Ness, Romeo

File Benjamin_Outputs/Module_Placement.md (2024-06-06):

The door, as previously designed by other contributors, was sufficiently water-tight - improving water-tightness was not one of our deisgn objectives. 

However, water ingress into the coolbox risks faster warming of the vaccines, due to [water's thermal conductivity being higher than that of air](https://en.wikipedia.org/wiki/Thermal_conductivity_and_resistivity). Additionally, the coolbox filling with water makes the device less accessible to users, and more frequently in need of maintenance. 

Hence it is important that our design does not compromise the existing seal mechanism, which is considered sufficient. 

Additionally, the existing design has a small ridge around the outside, in which the door sits when closed. This is where the door-sensing button will press into. 

The preliminary candidate designs for the placement of the electronics module on the door are as follows: (In each case, only the top layer of the door is drawn - the trapezial structure of the rest of the door extends downwards. The red semicircles represents the button, which sense when the door is closed.)



***Details of Specific Design Candidate 1***

- there a slot indented into the design of the door, which the electronic module clips into
- the open/closed button sensor protrudes out the side of the door

***Details of Specific Design Candidate 2***

- the electronic module clips onto the top surface of the door
- the open/closed button sensor protrudes as low as possible across the top surface of the door, low enough to still be pressed by surrounding ridges when the door is closed



<br />

**Assessment of Candidate Designs**

The requirements for a successful design in this area are:
1) Does not compromise water-tightness
2) Mechanically robust (difficult for module to break off; ideal if module is not the first point of contact when coolbox is dropped)
3) Does not significantly compromise insulation
4) Button is low enough that it presses against existing ridges in door design, for door-closed detection

Assessing the two candidates against these criteria:

***Shortcomings of Candidate 1, in which there is a slot for the electronics module to clip into:***

- ****Water-tightness is compromised****.
  The button protrudes out the side of the door rather than across the top face. When the module (including the button) is removed, this will necessarily leave a gap in the water-tight seal, thus allowing for water ingress when the module is charging.

***Shortcomings of Candidate 2, in which the module clips onto the top face:***
- ****Mechanical roubstness****
  The entire module protrudes significantly above the top face of the door, making it the first point of contact for the coolbox if dropped upside down.
  Any impact-absorbing features on the top of the door to mitigate this would need to be large - at least as tall as the electronics module, worsening aesthetics and increasing material costs
- Water tightness is not compromised, as the button slides along the top face, above the existing seal which is left intact. 

<br />

In their best possible arrangements, both of canddiates 1 and 2 comfortably satisfy the insulation and button position criteria (the insulation criteria is examined in more detail later). 

<br />

Following this analysis, a third candidate design is proposed, which is a hybrid of the previous two. 



***Details of Specific Design Candidate 3***

- there a shallow slot indented into the design of the door, which the electronic module clips into
- the open/closed button sensor is across the top face of the door, so does not compromise water resistance and is low enough to be pressed when door is closed
  
As it meets all four of the the design requirements, this is design which will be pursued into the physical prototyping stage. 

<br />

Hence we have our final (theoretical) design!

After making the module into a [physical prototype](https://github.com/Technology-for-the-Poorest-Billion/2024-ideabatic-beam/blob/main/mechanical%20design/handover%20notes/final%20design%20dimensions.md), it is essential to prove that our design still meets the performance requriements on all five of the dimensions. Hence, a [final feasability analysis](https://github.com/Technology-for-the-Poorest-Billion/2024-ideabatic-beam/blob/main/Benjamin_Outputs/Final_Design_Feasability.md) was performed.

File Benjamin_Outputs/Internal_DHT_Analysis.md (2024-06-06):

Inkeeping with the conservative analysis principles outlined (**insert hyperlink here**), 
an analysis of the feasibility of the DHT being kept inside the module housing was carried out. 

<ins>The Problem to be Solved</ins>

- Our general design is Candidate 5, which integrates the temperature sensor into the electronics module. Heat will be dissipated by the electronics module (powered by two AA batteries).

<br />

Will this heat cause the temperature inside the module to be significantly different from the actual temperature outside the door?

<br />

<ins>Validating Analysis: Worst-Case Assumptions</ins>

1) All of the power consumed by the circuit is produced as heat
2) The internal resistance of the batteries used is at the lower end of the [average range for AA batteries](https://www.researchgate.net/figure/Average-internal-resistance-of-AA-batteries_tbl2_379429848), as this gives the highest heat production.
3) The 'load' (the circuit supplied by the batteries) satisfies the maximum power transfer theorem, as this gives the highest heat production.
4) Convective heat transfer out of the module casing is neglected; only conductive heat transfer is analysed

<br />



#### [Figure 1](https://www.google.com/url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): Maximum Power Transfer Theorem

<br />

<ins>The Analysis</ins>

<ins>Maximum Heat Power Produced</ins>

Two AA batteries

$\implies {R_{in,total}}$ = $\{2R_{in,single}}$

Maximum Power Transfer Theorem: Resistance of Load = Internal Resistance of Batteries

$\implies {R_{L}}$ = $\{R_{in,total}}$

$\implies {R_{total}}$ = $\{2R_{in,total}}$ = $\{4R_{in,single}}$

$\{P_{total}} = \frac{V^2}{\{R_{total}}} = \frac{V^2}{\{4R_{in,single}}}$

Maximum Total Voltage = 3V (1.5V per battery); Minimum $\{R_{in,single}}$ = 0.19 Ω

$\implies$ $\{P_{total}} = \frac{3^2}{\{4\times0.19}} =$ 11.84 W

<ins>Heat Conducted Away</ins>

<br />

- In order for heat produced inside the electronics module to be conducted away, it is physically necessary for the temperature inside the module to exceed the actual external temperature. 

- Allow the temperature inside the module casing to exceed external temperature by 1ºC (∆T=1).

#### Check that the cool life prediciton is not drastically affected by a 1ºC overestimate in the ambient temperature:

- Plugging into the [temperature prediction algorithm](https://colab.research.google.com/drive/1pOM9zMMuzmkzLNehpk7Lr7O0WtXEk16u?authuser=1#scrollTo=-TuyIuoOHyXr), the effect is quantified:



#### Figure 2: Overestimate in ambient temperature results in only a 4% underestimate in cool lifetime (acceptable)

<br />
<br />

#### For a 1ºC maximum overestimate:

$\dot{Q} = \frac{∆T}{\{R_{th}}}$

To conduct away enough heat to remain in the acceptable range, $\dot{Q} \ge$ Heat produced $=$ 11.84 W

$\implies {R_{th}} = \frac{l}{\lambda\times{A}} \le \frac{1}{\{11.84}}$ = 0.084 KW<sup>-1</sup>

$\lambda_{aluminium}$ = 237 Wm<sup>-1</sup>K<sup>-1</sup>

$\implies$ For an aluminium casing, $\frac{l}{\{A}} \le 237\times{0.084} =$ 19.9 m<sup>-1</sup>

If any part of the module casing is made with aluminium which meets this aspect ratio, then any other sections (eg the transparent section for screen viewing) can be modelled as parallel resistive components in the heat analysis, only further improving the cooling capability of the casing. Thus manufacturing the casing with a section of aluminium meeting the aspect ratio required is sufficient to ensure that the temperature measured remains within the acceptable range. 

Aluminium thermal conductivity:

https://www.ncbi.nlm.nih.gov/pmc/articles/PMC10144406/#:~:text=Aluminum%20has%20a%20thermal%20conductivity,1%2C2%2C3%5D.

Cost of aluminium sheeting:

https://www.aluminiumwarehouse.co.uk/products/1-5-mm-5251-h22-aluminium-sheet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¤cy=GBP&utm_source=google&utm_medium=cpc&utm_campaign=Pmax%20tier%201%20-%20others&utm_id=20993447663&utm_term=&gad_source=1&gclid=Cj0KCQjwsPCyBhD4ARIsAPaaRf3k0eqC-FZWQaHwsebMHXSQ9EdVMUEPBOZF0SQjGx6mZrish0z4w_8aAsqzEALw_wcB

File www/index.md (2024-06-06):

---
title: Electronics Module for Cold-Chain Assurance 
---

Quick links: [Team Strategy and Project Management.](/2024-ideabatic-beam/team.html) [Technical Summary.](/2024-ideabatic-beam/techsummary.html) [SDGs.](/2024-ideabatic-beam/SDG.html) 

## Ideabatic's Mission

cameroonstorydesktop
Source: [about.ups.com](
https://about.ups.com/ae/en/our-stories/innovation-driven/solving-the-cold-chain-challenge.html)

Current vaccine carriers use cooler boxes that are poorly equipped to handle their transport environment. Vaccines stored in average cooler boxes are shown to last approximately 4 hours in the field, which is simply not enough for last-mile journeys that can last up to 2 days in over 25ºC heat. 

b15aae5413891f4654121f47aa32fa63

Source: [heraldsun.com.au](https://www.heraldsun.com.au/)

Human error is also a problem, as healthcare workers may unknowingly leave cooler boxes open for long periods of time, especially during vaccine administration. Workers may also skimp out on the required number of icepacks, or place the vaccines and icepacks haphazardly. These mistakes significantly reduce the cooling lifetime of the vaccine carrier.



Source: [ideabatic.com](https://www.ideabatic.com/solution)

SMILE, or SMart last-miLE Cooling System, aims to combat these issues with a uniquely designed cooler box containing only one single ice pack that can keep 18 vials of vaccines cool for up to 4 days (120 hours), along with a self-closing door mechanism to reduce human error. The design is waterproof, is carefully insulated, and includes straps for comfortable carry as a backpack. Ideabatic also envisions SMILE to be used in other temperature-sensitive applications, as a more efficient and fail-proof alternative to other cooling boxes in the market.

## BEAM's Objectives

Ideabatic had been collaborating with different project groups to develop an electronics module that displays the temperature and remaining cool life as an add-on product to the SMILE device. The need for such a product was identified after some users relayed that they wanted to keep track of the temperature in the SMILE device to better ensure the vaccine is stored properly, and give an indicator of whether or not there is time to schedule visits to close neighborhoods.

Previous project groups have worked on different electronics housing and door slot designs, developing temperature and cool life prediction algorithms and door alert systems, and improving other mechanical features such as the self-closing mechanism and lid ergonomics. BEAM aims to build upon the work done by these previous groups, identifying the limitations of previous designs and improving on these features based on feedback given by SMILE's founder, Kitty Liao, and our own personal insight.



### Our goal: Modularise the electronics. Minimise the compromise to insulation.

## [Read about how we achieved this.](/techsummary.md)

Authors: Ness, Romeo

<!--
### To configure your website:

- The required files to run a basic website are included in the repository. We use here Jekyll to turn markdown files into html that will be automatically updated on the website. The component responsible for this is a GitHub action, which is specified in the folder .github/workflows. There is no need to change this file. However:

- In the settings of your repository, go the section "Pages", and select GitHub Actions in the drop down menu to indicate that this is the way you'd like the webpage to be generated.

- Each time you update the markdown files in the www folder of the repository, it will regenerate the web content. The address of the website will be:

```
https://technology-for-the-poorest-billion.github.io/[your repo name here]
```

- index.md is the root of your website. To link another page from here, located within the www folder, use the following syntax:

```
This is a [link](linkedpage.md) to interesting content.
```

Which results in:

This is a [link](linkedpage.md) to interesting content.

- Pay attention to the header of the markdown files in this section. It contains a title section that you will need to reproduce for each page to render them properly.

-->

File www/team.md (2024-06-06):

---
title: Team Strategy and Project Management
---

<!-- Statement about project management, explain the team work strategy. Reflect on what worked and what didn’t work, drawing constructive recommendations where possible. ~500 words, included in the webapge, git repo or github wiki. -->

## Our Team

Our project involved two main stages: design approach and practical design. The design component was further divided into electronics and mechanical aspects.

The three tasks were then each delegated to a group member based on their strengths and experiences. Benjamin was in charge of the design approach due to his strengths in communication and experience working with temperature prediction algorithms. Romeo was in charge of electronics design due to his experience in electronics prototyping with sensors, displays and Pi 4. Ness was in charge of mechanical design due to her experience with using various CAD software. These assigned roles were a good fit and allowed us to play to our strengths in this project.

The project was also an opportunity to learn new skills. Being in a team of people with diverse experiences also allowed team members to learn from each other. For instance, Ness was able to consulted Romeo on using 3D printers due to him having more experience.

A diverse team also produced conducive discussions where diverse and challenging viewpoints emerged, allowing us to develop better solutions through the sharing of knowledge and ideas. However, this makes the decision making process more time consuming which, under the time pressure, may have led to suppression of dissent that led to subpar decisions being made. Overall, the team worked well together and encouraged each other during difficult times.

## Project Management

Due to the tight time scale and pressure to deliver, our time management was suboptimal. Here are our major pitfalls:

1. We did not settle on a final design until very late in the project. An improvement would be to define the design strategy more clearly, starting from the feasibility study of different designs, such that the design direction of the project is set early on.

2. A lot of time was spent interfacing work between OpenSCAD and Solidworks. A more careful decision about which CAD package to use in design, for example using a list of pros and cons, would also allow for the final design medium to be determined earlier on.

3. We unknowingly ordered electronics from an overseas supplier, leading to delays in component delivery and having to push back subsequent timeline tasks. Ensuring that we order from local suppliers would be more time and cost effective in the future.

Although these setbacks hindered our progress, we were able to bounce back due to good communication and contingency planning early on:

1. Our project timeline included extra bandwidth in case of external, personal, or technical issues. This allowed more flexibility in our schedule that was proven necessary.

2. We had a comprehensive contingency plan that indicated alternative pathways or aspects of the project that could be omitted, such that we narrowed down our focus to complete the most crucial objectives when our time was constrained. This was helpful in ensuring we deliver the best product when facing time and budget constraints.
  
3. We met up regularly to discuss project progress, problems faced and important insights. This allowed for in-depth discussions that formed the basis of determining our project direction over time, and allowed members to brainstorm ideas quickly to problem solve roadblocks.

4.  We set up a group chat amongst the members, as well as a separate chat with out client, to communicate different aspects of the project easily when face-to-face meetings were not possible or not necessary.

Author: Ness

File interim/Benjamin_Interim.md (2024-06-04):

# Benjamin's Work done so far
<br />

## Formalising the primary design problem:
- electronics module with temperature sensor to inform algorithm and display for user
- module should be clip on clip off (opt in design, easy charging)
- minimise compromise to insulation
- target budget: £15 (batch size ~3000)

<br />

## Some additional context:
This project was taken on by a team last year, here is the progress they made and where they fell short:

- successfully made an electronic circuit that displayed the temperature and remaining cool life
- was not very modular, required removal of door which was tedious in practice.
- ambiguous in their final recommendation for position of the temperature sensor
- did not quantify the effect of the electronics module compromising insulation
- mechanical issues with door ergonomics, lack of protection for display screen

<br />

## Our Design Process

### Default Physical Arrangement

IMG_9413C2C4692F-1

*Why is there a 'default'? Shouldn't this be an open design problem?*

This is an open design problem, but it has a starting point.

The starting point represents the company's initial preferences, based on the work presented to them by previous contributors. 

Some of the key factors informing the company's initial preferences are: environmental/wear resitance of the electronics module and veracity of the temperature prediction. 

Part of the useful output of this project is a demonstration in quantifying and visualising the performance of candidate designs, as a means of justifying the design decisions made. This is useful in the immediate term, as an assurance to the company, and will be useful in the future, as it streamlines further work which might be done in incrementally improving the design we present. 

Therefore, in the subsequent design process, a five 'key performance indicators' were defined:

- Cost Effectiveness
- Veracity of Temperature Prediction
- Modularity/User-friendliness
- Environmental Resistance and Mechanical Robustness
- Insulation

<br />

Each candidate design is given a rating in each of these five dimensions. 

Each candiate's ratings across the board can be visualised by a radar plot:

An overall 'fit for purpose' score can then be assigned to each candidate, according to the formula below:

Score = (Rating in KPI 1) x (Rating in KPI 2) x (Rating in KPI 3) x (Rating in KPI 4) x (Rating in KPI 5)

A product-based scoring system is preferred because 

#### Communication and justification of our design decisions is important!

<br />

# Communicating Design Decisions

To justify design decisions, score each in the following dimensions, resulting in Key Performance Indicator

Radar plot for visualisation of rankings:





<br />
<br />

Since each dimension critical, a better KPI might be a weighted *product* of the scores in each dimension. 

- which candidates to proceed with
- relative strengths and weaknesses
- areas for improvement 

<br />

# The candidate designs
IMG_548055A1CA77-1

<br />
<br />

## 1: Direct Axial Connection - Feasability Assessment



<br />
<br />

- This is the design prototyped by last year's group
- They neglected the obvious risk of insulation compromise

### Quantifying Compromise to Insulation

- Manufacturing and design interdependence:
Wiring ~ 2 mm. Door made of PBS, manufactured by casting ⇒ ± 1 mm

IMG_BBFAF02D5158-1

- Optimising Geometry: Optimal housing for wiring is 'figure 8' shaped, results in: 6.3mm<sup>2</sup> wiring, 20.2mm<sup>2</sup> air.  

- Computing thermal resistance per unit depth of door;

- Running simulation to quantify effect on cool lifetime:



Cool lifetime at 24ºC ambient temperature reduces from 97.5 hours to 14.5 hours.

This is worst case (can cover ends etc.), but clearly worth worrying about! 

<br />
<br />

## 2: Wireless Communication - Feasability Assessment

Cost of making wireless (two microcontrollers cheaper than buying wireless temperature sensor):

Pi Pico → Pi Pico W: £2

Wireless module microcontroller (ESP8266) to communicate with Pi Pico: £4

So adds £6 to the single-unit price of electronics module

Might *just* be feasible if there are no other cost incurred (see below)

### Budget Feasability

| Part Description | Single Unit Cost | Bulk 100+ Unit Cost |  |
|-|-|-|-|
|Raspberry Pi Pico| £4.02 | £3.14 | 
|DHT22| £4.74 | £3.56 | 
| OLED Display | £10.19 | Pending (supplier contacted) ~ £7.95 |  

#### Per-unit cost for 100+ units: £14.65



#### Optimistic Per-unit cost of core electronics module for 3000 units: £11.37 
(Assumes continuation of logarithmic pricing trend, such that per-unit cost falls to 60% of single-unit cost)

<br />

Hence,
**Single-unit cost that could feasibly be added: (15-11.37)/0.6 = £6.05** ≈ £6

<br />

# Benjamin's Personal and Technical Development
- Redefining the objectives: what is really necessary?
- Discussing changes of direction with project partner
- Applying conceptual engineering skills to a real problem (eg heat transfer, manufacturing + design interplay, circuit design)
- Learning how to develop code in Raspberry Pi's Micropython IDE Thonny (not shown in this presentation)
- Clear documentation and communication of design decisions for partner
- Communicating directly with suppliers
- Budgeting, including obtaining quotes for bulk orders
- Project direction and management

**How I have learnt/acquired these developments**: Direct exposure by doing

<br />

**References**

https://mathworld.wolfram.com/Lens.html

https://thepihut.com/products/raspberry-pi-pico-w?src=raspberrypi

https://kunkune.co.uk/shop/esp32-esp8266/esp8266-nodemcu-v2-cp2102-lua-wifi-development-board-module/

https://chachart.net/radar?lang=en

https://wokwi.com/projects/398954539831627777

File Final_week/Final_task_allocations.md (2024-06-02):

## Benjamin

### Stage 1: Overall Design

#### Possiblilities considered for overall design:
- The five candidates shown
- Feasibility assessments and spider diagram ranking of each one; justify pursuing the uni-modular design, with a specific focus on improving the environmental resistance
- Single mode design also has the disadvantage of having no information about when the ice packs have just been put in.
- Need a manual 'reset cool lifetime' button. What if they forget to press button? What if they accidentally press it?
- Put the button on the bottom of the module to be automatically pressed when module reloaded: difficulties with each method, this is another user problem to be solved. 

### Stage 2: Solving the temperature sensor problem
- Compare the two designs for temperature sensor: external, waterproof sensor (cost and mounting issues) vs internal DHT22 (innacurate temperature issue - back up with conductivity requirement, cost)
- upper limit heat corrpution effects: heat power = electronic power for batteries and display
- Output: the minimum surface area that needs to be made with conductive material, show that it is within budget + the area with 

### Stage 3: Solving the door switch and button problem

- Considered cutting out a large region, inserting module to fill the gap, but this compromises water resistance when module removed (either by leaving water seal intact but providing a parallel path straight through, or but taking out a chunk of the water seal)
- Also considered mounting entire module on the top of the door (could do a mechanical impulse analysis) but makes it less drop-resistant (module breaks off) and requires outside ridge of box to be raised so that button can still be pressed, also probably a less secure clipping mechanism if not indenting into door
- Final prototype solution (copy in conceptual drawing): top of module slightly indented so it goes flush with top of button arm, with is entirely on top of door so as not to compromise water seal + Plastic boxes to make entire things rectangular, giving better mechanical robustness
+ Cylinders with hemispherical ends at each corner to give drop protection
- Means that when module is removed, the door is still fully functional and has minimal compromise to its insulation (calculation supporting)

<br />
  
- Going to need a way of waterproofing buttons: solid casing + rubbery button topper to prevent water ingress. 
- Considered possibility of an auto-press button for resetting the timer (see above)

<br />

- Feasability assessments and rankings, clearly communicating design decisions

<br />

- eliminate all alternative designs on feasibility grounds
- make the compartment out of three things: cheap, clear, conductive. 
- material selection (conductivity, heat resistance, cost)
- graphene may not be a mature material in 3D printing technology
- manufacturing complexity
- rough sketch of preferred design

<br />

- Need manual button to reset cool life: where to put button? Difficult to access place - maybe aturomatically pressed when module clipped back on, solves water resistance (lifetime of button?)

<br />

## Romeo
- Calculate expected power consumption of electronics module, justifying choice of battery (cost, recharge/overcharge?). PASS POWER CONSUMPTION DATA TO BENJAMIN.
- How long are AA batteries expected to last? Is the electronics module always on?
- Design and implementation of the (capacitor-based?) circuit for door switch detection
- Full circuit diagram, including temperature sensor, OLED, microcontroller, batteries, capacitor, resistor, door switch, user-interface button
- Assemble electronics module (screen working/updating + switch informing buzzer) and test. PASS DIMENSIONS OF MODULE TO NESS. 
- Getting it working with Code 
- Mount it into correct shape (collb w Ness)

<br />

## Ness
- Cad model of the actual case, including a see-through compartment and a conductive compartment, ready to be 3D-printed.  (Romeo tells dimensions after assembling circuit)
- Cad model of the door that is receptive to the case being clipped on (choose and justify clipping mechanism)
- Choose materials for module casing: (i) base module. (ii) transparent section over screen. (iii) **conductive section is aluminium, with thickness/area < 19.9**. (iv) rubbery casings for buttons.
- Constraints for choosing materials: - need to be easy to join together (suggest methods for joining, possibly including cost and efficiency considerations), - each needs to be thick enough to have sufficient mechanical robustness
- Outline file compatibility issues between OpenSCAD and SolidWorks
- 3D print and assemble door + case of electronics module (collaborate w Romeo): *Working prototype*

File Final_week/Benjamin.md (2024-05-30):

# Deliverables:

- Further feasability assessments, spider rankings on overall designs to justify strategy: single module, focus on improving environmental resistance
- Including update to the axial connection feasibility assessment: incorrect premise originally; need to consider series thermal resistance to all the internal insulation
<br />

- Calulcation proving temperature sensor can be incorrput if certain area of conductive material used for module casing: shows why preferable to external temperature sensor
(include cost assessment of using this much conductive material); with upper limit of heat power produced coming from battery power considerations

- Probably first requires material selection (graphene? silicon?)

<br />

- Drawings of candidate designs for temperature sensor + switch; show the paths for water ingress for the indent desing, and the mode of breakage + cost of raising outside for top-mounting design

- User-oriented button logic to inform button position (accidental pressing? Forgetting to press?)

- Final prototype sketch, incl. cyclinder-hemispheres

- Calculation showing that the loss of thermal resistance due to slight indent on module is negligible.
  
- Overall costing assessment of final design

<br />

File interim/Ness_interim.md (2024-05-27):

## Main objectives
- Modularised electronics: create a compatible casing and slot.
- Improve ergonomics: lip of lid and torsional spring parameters.
- Transfer of models to open source CAD: increase accessibility for future design modifications.

## Design considerations
- Slot for connector and temperature sensor on door.
- Door lip should be a flat surface, so a new design is needed for the lip as last year's group is raised.
- Soft ridge around electronics module slot (preliminary OpenSCAD design shown with hard ridge).

- Ridges on component interfaces to facilitate joining and compatability.

plastic-to-metal-300x268

## Tasks completed
- Learned basic skills in OpenSCAD and exporting .STL files.
- Preliminary design of electronics module casing on OpenSCAD ready for future compatibility adjustments.

- Transfer of SMILE design files into OpenSCAD (chassis, casing and door) and assemble components.

- Edits of door design on Solidworks (connector placement, temperature sensor slot).
- Compiled literature on door ergonomics design and reviewed previous designs.

## Issues faced and solutions
Understanding OpenSCAD syntax:
- Simple but required time to get used to and not as intuitive as Solidworks.
- Consult online forums and wiki.

Assembling components:
- Difficult to assemble components, need to constantly refer back to Solidworks file to check how they fit.
- Scales on OpenSCAD are not precise, dimensions of downloaded .STL models are not well defined.
- Used online .STL measurement tools to obtain precise measurements.


Limitations with editing .STL files:
- Using difference/intersection commands to edit .STL imported files becomes rather buggy.
- Unable to edit directly on OpenSCAD, therefore instead modifying door using Solidworks as modelling a new door in OpenSCAD is too difficult.
- Download as .STL to interface with other components in OpenSCAD.

Solidworks files to Github storage:
- Stored on a One Drive for now, need to figure out transfer.

Delay in electronics delivery:
- Unable to settle on design at this stage, delays in design.
- Easily adjustable code.

## Next steps
- Adding ridges to the casing/casing cap and casing bottom/door slot interfaces to facilitate joining of components.
- Finish first door lip design modification on Solidworks.
- 3D print door to start testing ergonomics.
- Once electronics team has a model of the electronics components, edit the casing and door hole dimensions.
- 3D print new door top and casing.
- Assess success of design and give suggestions for improvement.

## Technical developments
- Practiced using OpenSCad and interfacing with Solidworks through .STL files.
- Brushed up on Solidworks skills.
- Github documentation of OpenSCAD code.
- Learned design strategies for in field use (preventing drop damage).

Next:
- 3D printing.
- Iterative design.

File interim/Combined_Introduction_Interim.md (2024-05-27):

# Problem Context
Ideabatic has been collaborating with many different project groups to develop a temperature display electronics module as an add-on product to the SMILE device. The need for such a product was identified after some users relayed that they wanted to keep track of the temperature in the SMILE device to better ensure the vaccine is stored properly.

Previous project groups have worked on different electronics housing and door slot designs, developing temperature and cool life prediction algorithms and door alert systems, and improving other mechanical features such as the self-closing mechanism and lid ergonomics. This project aims to build upon the work done by these previous groups, identifying the limitations of previous designs and improving on these features based on feedback given by Kitty Liao (founder of SMILE) and personal insight.

#### Primary goal: (i) Make the electronics modular, (ii) minimise the compromise to insulation, (iii) improve erognomics of door, and make CAD open-source

Secondary objectives (only if primary satisfied): 
- Implementing GPS tracking and data logging to external storage (as opposed to within Pi) on the electronics module
- Adapting the temperature prediction algorithm to account for the door open vs door closed

# Teamworking

<br />

**Benjamin's role:** The design problem, project management, also working with Romeo on electronics and software implementation

<br />

**Romeo's role:**

The electronics and code (already prepared some code in the Raspberry Pi Pico's compatible Python IDE Thonny, 
which should work, just needs to be adapted to the specific temperature sensor and tested with the circuit once assembled). 

Romeo more suited to how the electronic circuit should actually work, and choosing the appropriate components, along with combining them all into a module that then slots into the door.
(for example the details of how the switch could be implemented)

<br />

**Ness' role:**
Design the electronics module casing and door using OpenSCAD.
3D print designs to assess component compatability and ergonomics.
Transfer drawings of previous and current designs from Solidworks to OpenSCAD to facilitate future development.

<br />

**Teamwork:**
- Have been meeting multiple times a week to discuss project ideas
- Assisting each other in assigned tasks
- Constantly discussing project direction and progress on Whatsapp
- Also in regular contact with project partner
- Expect in-lab hours to increase as electronics components arrive
- Keeping github up to date

<br />

Personal and technical developments, and work done so far will be presented later by each member.

<br />

## Issues encountered:

- Actually deciphering all of the available data (not particularly good file management from partner or previous team)
- Some design assumptions have been 'locked in' to partner's preferences by previous iterations of the project. Careful communication of deviations required. 
- Surprisingly long lead time on component orders (first order of components still haven't arrived, second order made today)
- Budgeting becomes difficult as we are looking at a large batch size (3000)

<br />

## Steps taken and future steps to overcome issues:

- During lead wait time, conceptual aspects of the project such as feasability assessments and CAD translation have been carried out
- Explicit communications with project partner about the intentions to revise design assumptions
- Making direct contact with contributors to previous projects to understand rationales and recommendations
- A revision of the objectives to ensure we can deliver useful output in the timeframe
- Direct contact with suppliers of electrical components made to negotiate bulk price discounts

# Updated project timeline

<br> On track with original timeline, small adjustments made to the remaining tasks left. We have used the extra time originally scheduled, noting that the parts took longer to arrive than expected.

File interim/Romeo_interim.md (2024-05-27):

# Romeo's role:
Predominantly focussed on the physical aspect of the electronics module. This includes interfacing the electronics with each other, along with finding the best way to implement the electronics module that best preserves insulation. 
<br> Will also be dealing with the software implementation.

# Personal and technical development
- Personal knowledge of all the parts and researched how best to combine them.
- Getting used to developing with the Pi Pico via Thonny.
- Improving logic and coding ability regarding software.
- Will have to learn how to appropriately deal with the button inputs, will do this via interrupts.

# Tasks completed
- Sent order for the electronic components required; ETA Tuesday 28/05.
  - This included the following: Raspberry Pi Pico, DHT22 temperature sensor, an OLED screen, buttons, and an AA battery holder, among other components for testing.
- Brainstormed different ideas with Benjamin to narrow down different designs to detect the door being open/closed.
- Very rough software draft made, but will require testing to determine and overcome hurdles.
<br>

# Main tasks remaining:
- Order any further parts required when possible.
- Combine the electronics into an "electronics module", working with Ness to build a case via 3D printing. 
- Designing a way to interface the electronics module with the internal temperature sensor. Current method is to use a pair of male/female headers to connect the module to the internal temperature sensor.
  - Using a bluetooth temperature sensor that is embedded among the vials is a possible solution, albeit expensive and possibly complicated.
- Trialling methods of detecting the door state.
- Decide the best cable routing method.
- Refining the code to make it work well with our prototype.

### Notes to tackle:
**Water resistance:** Electronics module prototype won't be water resistant, which could be especially difficult noting that the module would involve a screen, buttons, a USB port for charging, and potentially a micro SD card slot, though for this we consider having everything only accessible inside the casing. 
<br> This is a conceptual prototype, and the external case/backpack is highly water resistant, so even as a protoype we don't see this becoming an issue.

# Issues
All work done has been theoretical, so the main issues that have arisen have been compatibility issues. 
<br> The main problem we are currently facing is deciding which paths we wish to explore and which aren't worth exploring, especially considering the limited time we have left. To best tackle this, we have looked at each choice, expanded upon them in detail looking specifically at usability and cost, and explored them as best we can to see which will be most fruitful in our case.

## Methods of detecting the door state
- Button switch that is pressed when the door is closed, as the last years team. 
  - Will need to be mounted at the edge of the door.
  - Faces issues with cable routing.


<br>

- An open circuit that is shut when the door closes, likely done through two open contacts that conduct via a plate when the door is shut.
  - Will potentially have issues with corrosion/lifetime as exposed with the door.
  - Faces issues with cable routing.


- Software based method: If we do use two temperature sensors, we can measure the internal temperature sensor, comparing this with the external temperature sensor to detect whether the door is open.
  - Doesn't require further cable routing.
  - Based on two temperature sensors, which may not be included in the final design.
  - Will face issues with the door being partially open, for example being propped open by a pen, though if there isn't significant heat loss transfer from internal temperature sensor this may not be an issue.
  - Accuracy will likely face issues when it comes to the end of the cooling time. 
- Distance/proximity sensors, such as the ultrasonic sensors used in the IDP project in IB.
  - Can be found for cheap (£2).
  - Often have minimum ranges of 2cm+ which will compromise insulation, but this could possibly be leveraged to our advantage.
  - Can be bulky.
- Issue with cable routing.
- Photo Interrupter Sensor, which detects when an infrared beam between a transmitter and receiver is blocked.
  - Relatively cheap (£3.90).
  - Would need to be mounted onto the edge of the door, with a corresponding part required to block the beam.
  - Issue with cable routing.

## Mounting the electronics module
The plan is to have these connectors, the male side attached to the module, with the female side attached to the door, allowing plug and play capability. <br>


## Methods of internal cable routing for the internal temperature sensor/other internal components
See Benjamin's work

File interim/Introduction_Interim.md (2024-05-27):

# Problem Context

Ideabatic has been collaborating with many different project groups to develop a temperature display electronics module as an add-on product to the SMILE device. The need for such a product was identified after some users relayed that they wanted to keep track of the temperature in the SMILE device to better ensure the vaccine is stored properly.

Previous project groups have worked on different electronics housing and door slot designs, developing temperature and cool life prediction algorithms and door alert systems, and improving other mechanical features such as the self-closing mechanism and lid ergonomics. This project aims to build upon the work done by these previous groups, identifying the limitations of previous designs and improving on these features based on feedback given by Kitty Liao (founder of SMILE) and personal insight.

# Teamworking

Benjamin's role: Project management, The design problem

Romeo's role:

The electronics and code (already prepared some code in the Raspberry Pi Pico's compatible Python IDE Thonny, 
which should work, just needs to be adapted to the specific temeprature sensor and tested with the circuit once assembled). 

Romeo more suited to how the electronic circuit should actually work, and choosing the appropriate components 
(for example the details of how the switch could be implemented)

Ness' role:
Design the electronics module casing and door using OpenSCAD.
3D print designs to assess component compatability and ergonomics.
Transfer drawings of previous and current designs from Solidworks to OpenSCAD to facilitate future development.

Teamwork:

Personal and technical developments will be presented later by each member.

# Summary of work done

## Issues encountered:

- actually deciphering all of the available data (not particularly good file management from partner or previous team)
- surprisingly long lead time on component orders (need to order all components we will need today if not before this presentation)

## Steps taken to overcome issues:

• Update the project development time-line and present a plan for completion.
• Present a summary of team members' personal and technical development (what have you learnt and how have you learned it?);

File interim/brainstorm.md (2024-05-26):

# How do we know if the door is closed/open

- external contacts that meet at a plate to tell us if it's open
issues with corrosion/lifetime
potential issues with fatigue

- comparing the difference in temperature between the two temperature sensors
issues with 
can also compare the internal with the predicted

- do we actually need the internal sensor
algorithm simply uses the external sensor
need to contact last years team

- for connection to internal sensor:
  wires going straight through down the door
  wiring around -- issues with wear
  going through metal hinges/through door switch contact

- button switch

- potentially measure angle of door? very complicated

- ultrasonic/infrared distance sensors?

- something using the hinge as electrical contacts???

- internal sensor preferred for mounting stability, reduces influence of electronics heating corrputing, better accuracy (fewer components whose thermal resistances need to be estimated)

# How will we connect the internal sensor to the external module?

// # PROTOTYPE/DESIGN FOR WIRELESS CONNNECTION

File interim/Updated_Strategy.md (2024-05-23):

Focus on incremental improvement, building on what the previous team has done. 

# Primary goal: Make the electronics modular, minimising the compromise to insulation. 

Strategy:

1) State the design problem/constraints:
   
   (i)  why we need internal and external temperature sensors,

   (ii) why they need to be connected (why wireless connection isn't feasible),
   
   (iii) why it needs to be modular (minimise insulation - metal connections naturally oppose this objective, easy charging)

   (iv) why it needs to be thin (for usability, damage prevention - helped by ridges around module)
   
   (v) why we need an open-closed sensor in door and beep
  
2) Obtain design possibilities

- Brainstorm various ways to achieve the electrical connections required
- Eliminate some possibilities for feasability reasons (eg compromises insulaton, ergonomics, including cost, eg for wireless solution). Quantify where possible. Document this process. 
- Finalise some candidates which are worth exploring by prototpying (one, two or three designs)

3) Assemble the electronics as a stand-alone circuit. Just get it working.

4) Build prototype(s). This is the final output. 

# Secondary goals:
Only do these if primary goal is complete.

- MicroSD for datalogger added onto circuit
- Calculation for adapting thermal resistance when door is open, to inform how the temperature-sensing algorithm should be updated when the door sensor tells us the door is open

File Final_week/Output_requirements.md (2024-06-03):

# Website
- targeted to general public
- what the overall product is, what you have added to it

- Be explicit about what we are trying to design:
- The door should work whether people order the electronic version or the non-electronic version of the SMILE

- Be explict about what the previous group did: specifically about what their temperature algorithm does, since we are using this

# Presentation
- Slides + Camera on Zoom recording. Monday evening. 
- All insights into the problem, basically everything you had to consider to get to the final output, but without the excruciating detail

# Github Repository
- Readme acts as Contents page
- Formalise the design problem
- Be explicit about anything that you did but is not presented, or anything you did not consider and why, and future steps
- Use hyperlinks but make a clear progression through the entire repository

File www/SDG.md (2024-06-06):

---
title: Sustainable Development Goals
---

[Ideabatic's website](https://www.ideabatic.com/) identifies the five most relevant of the [United Nations' Sustainable Development Goals](https://education.nationalgeographic.org/resource/sustainable-development-goals/).  



Our work primarily contributes to three of these five goals, in the following ways:

## Good Health and Wellbeing
Tackling good health and wellbeing is the priority of the cool box. The addition of the electronics module aims to reduce the vaccines used dangerously by informing the user when it is no longer safe to use them.  

## Reduced Inequality

- Targeted towards developing economies, the addition of the electronics module to the SMILE device allows for better information for administering vaccinations.

- As it is typically poor countries need these, this reduces health inequaity globally

##  Responsible consumption and production

The electronics module is built with this in mind. The final prototype takes rechargeable batteries and has an unbound theoretical lifetime when used correctly. We have also designed it to have components that able to be replaced.

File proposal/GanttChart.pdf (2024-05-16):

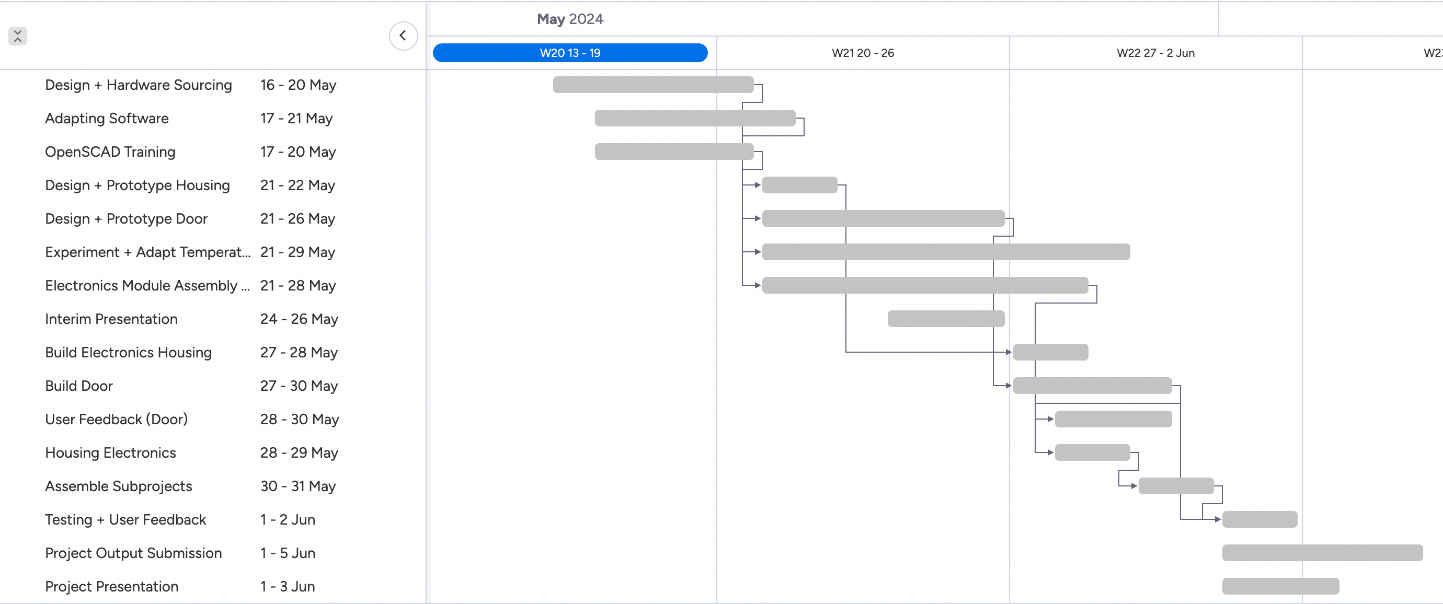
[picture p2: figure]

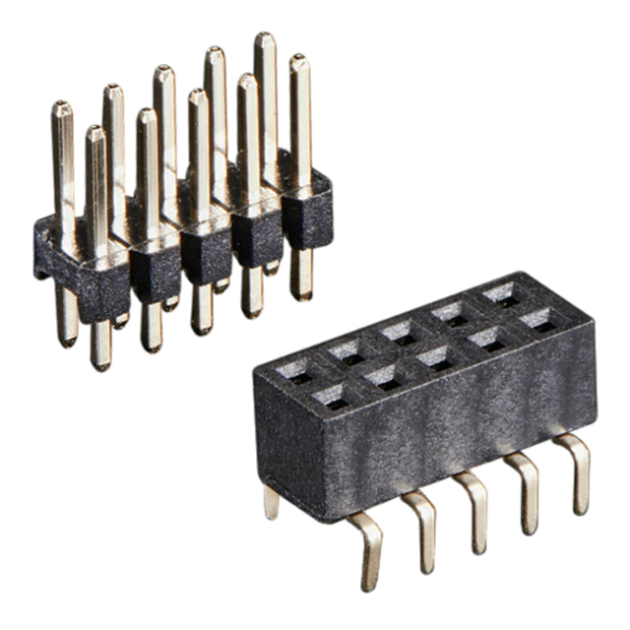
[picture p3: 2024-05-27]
interim/assets/Connectors.jpg

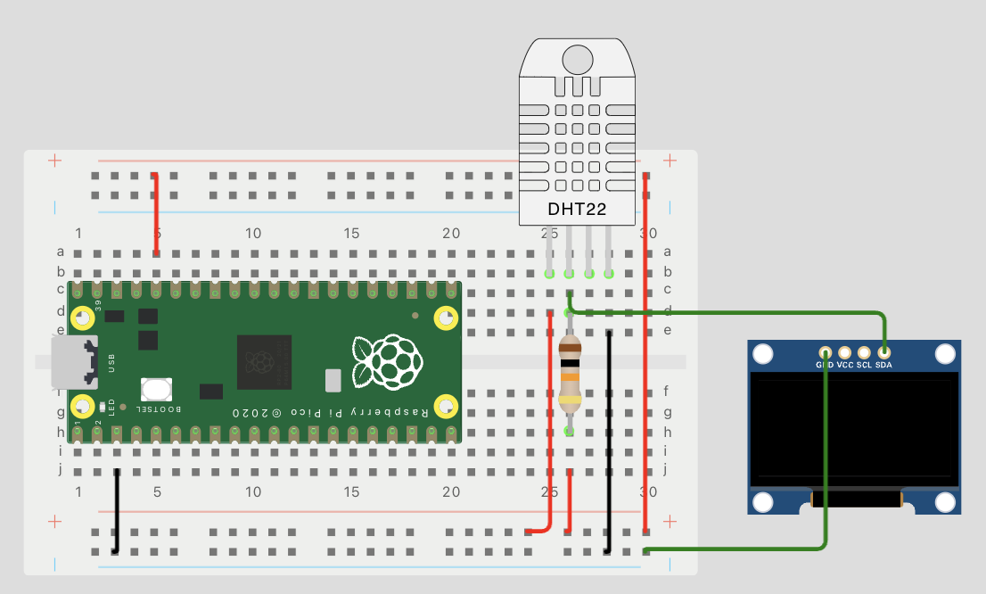
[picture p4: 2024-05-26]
interim/assets/Screenshot 2024-05-26 at 15.01.22.png

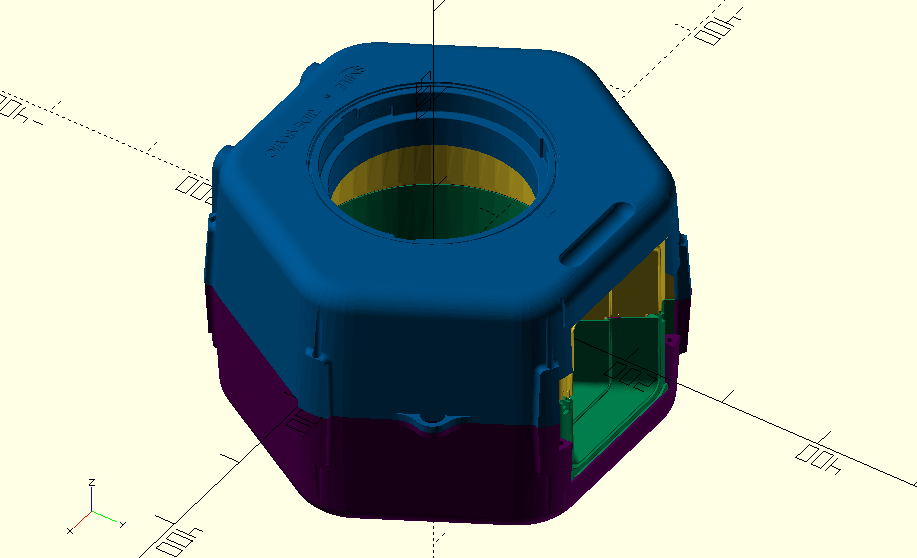
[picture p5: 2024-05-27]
interim/assets/Screen Shot 2024-05-27 at 12.08.57.png

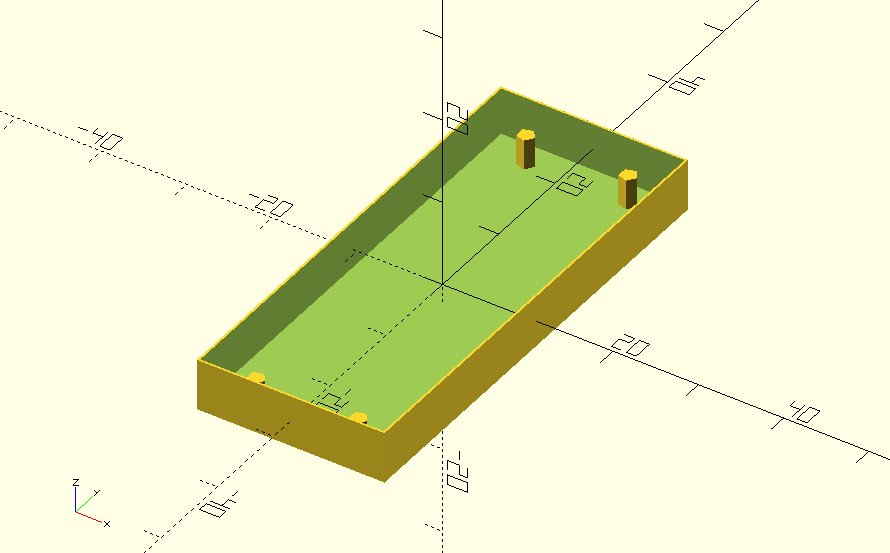
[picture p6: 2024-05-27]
interim/assets/Screen Shot 2024-05-27 at 12.02.42.png

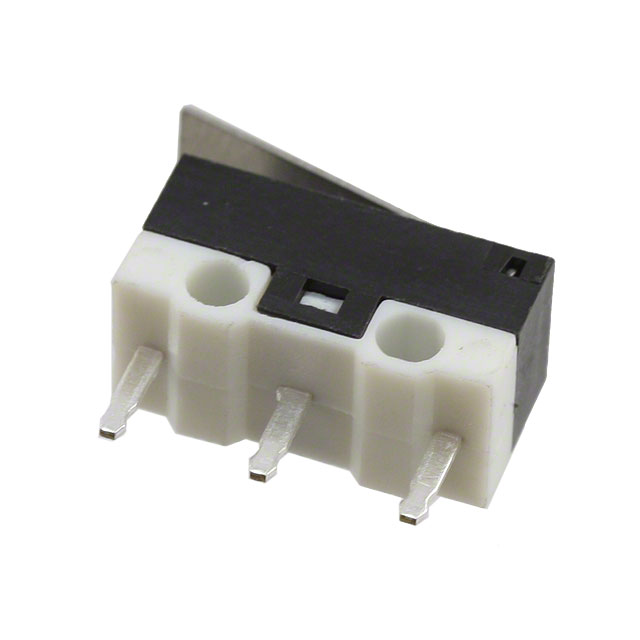
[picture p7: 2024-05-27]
interim/assets/Switch.jpg

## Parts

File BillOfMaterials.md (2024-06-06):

The following table is a collection of all items used in the final product. [For more detail, and recommendations on further improvements click here.](https://github.com/Technology-for-the-Poorest-Billion/2024-ideabatic-beam/tree/main/code)

|Description|	P/n or order code|	Unit Cost (exc. VAT)|	Quantity|	Link|
|-|-|-|-|-|
|Raspberry Pi Pico|	2648-SC0915CT-ND	|£3.22	|1|	https://www.digikey.co.uk/en/products/detail/raspberry-pi/SC0915/13624793 |
|Temperature Sensor (DHT22)|1738-1039-ND|	£4.74	|1|	https://www.digikey.co.uk/en/products/detail/dfrobot/SEN0137/6588461 |
|Switch|	EG4923-ND	|£1.02|	1|	https://www.digikey.co.uk/en/products/detail/e-switch/SS0750301F020P1A/2639077 |
|Button|	CKN10834-ND|	£1.12|	1|	https://www.digikey.co.uk/en/products/detail/c-k/PS-12C02-F-NS/7056058 |
|AA Battery holder	|36-2462-ND	|£0.98|	1	|https://www.digikey.co.uk/en/products/detail/keystone-electronics/2462/303811 |
|Wires (Dupont male to male) | 	4526-ZW-MM-20-ND	|£4.18	|1	|https://www.digikey.co.uk/en/products/detail/busboard-prototype-systems/ZW-MM-20/19200346 |
|OLED Display	|61-6338	|£4.98|	1|	https://www.rapidonline.com/winstar-wea012832flpp3n00000-oled-cog-128x32-yellow-0-91-on-pcb-i2c-61-6338|
|3V Buzzer|	35-3592|	£2.15|	1|	https://www.rapidonline.com/rvfm-3v-electronic-buzzer-with-10cm-lead-35-3592|
|AA Batteries (pack of two)|	18-1092|0.579	|1	|https://www.rapidonline.com/gp-gppcc15kc005-zinc-chloride-cell-aa-battery-pack-2-18-1092|

Total cost: £22.97 

These products were ordered from two websites: digikey and rapidonline. Note that digikey ships from USA, and so has around a week lead time.

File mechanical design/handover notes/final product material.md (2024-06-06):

### Final product material design

Module base - plastic injection moulding: 
- SMILE is already produced using a similar method, no additional resources needed
- Good for complex shapes like socket holes

Module top - aluminium forging:
- For conducting heat away from electronics in module (mentioned before)

Display screen - 3mm acrylic sheet:
- Protection of screen and ensuring watertight seal of module

Buttons - PVC switch cover
- Ensuring watertight seal

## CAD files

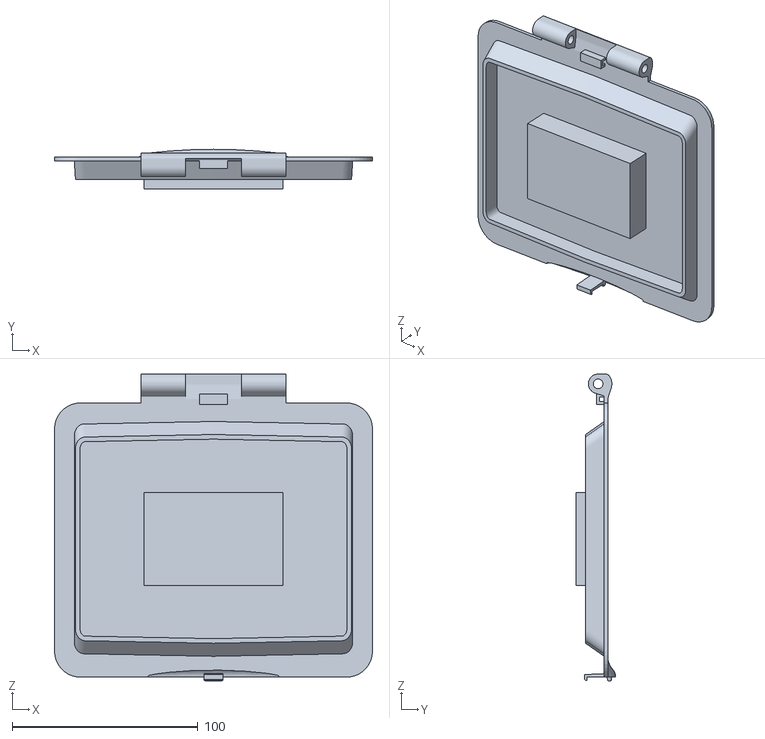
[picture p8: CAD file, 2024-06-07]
mechanical design/CAD/.STL files/Door-Top Part.STEP.STL
171.0 x 21.2 x 165.0

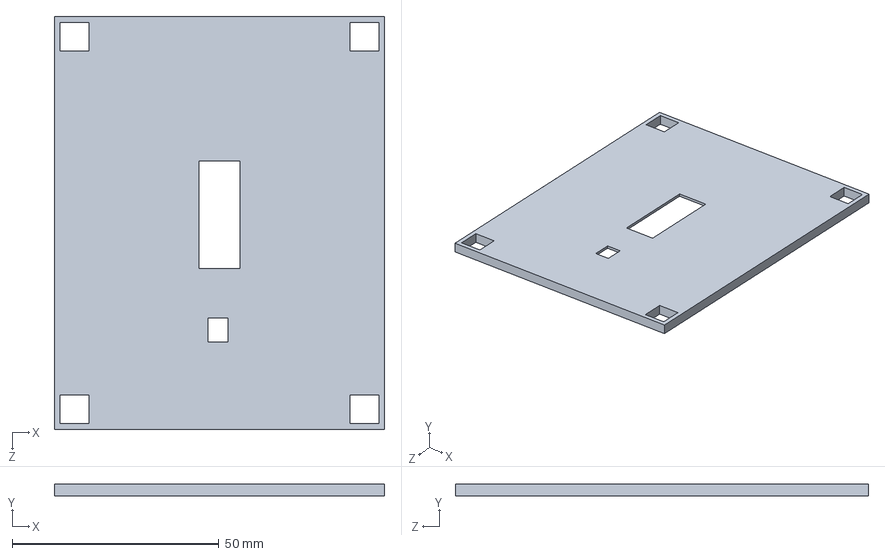
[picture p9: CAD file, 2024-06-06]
mechanical design/CAD/Solidworks files/Module casing top 2024.SLDPRT
80.0 x 3.00 x 100.0 mm

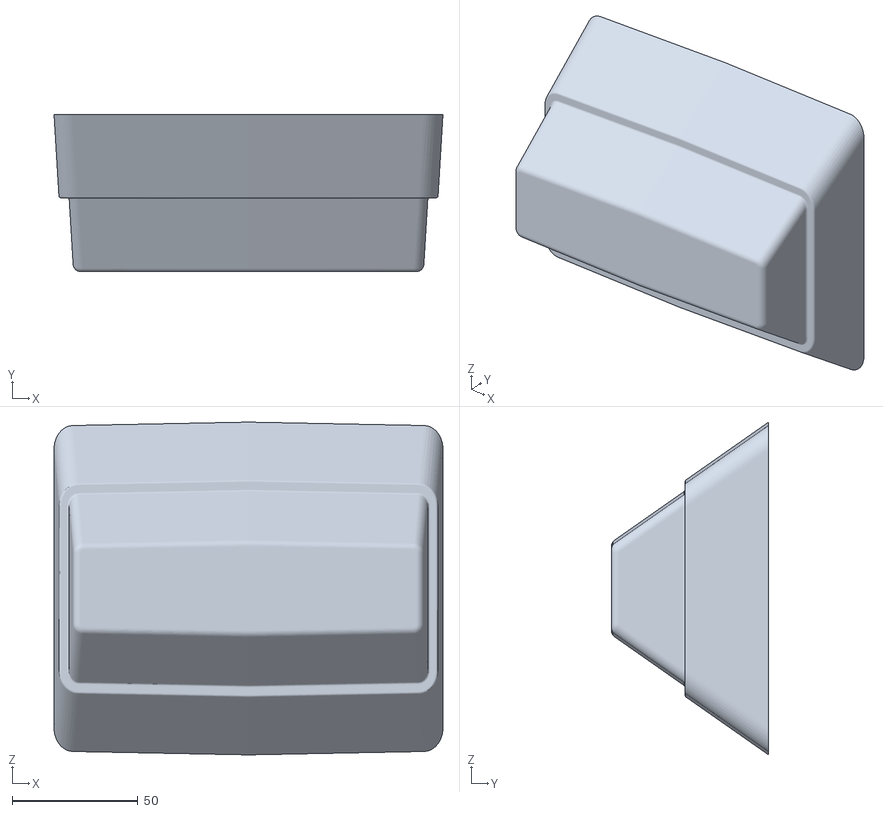
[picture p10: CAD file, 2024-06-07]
mechanical design/CAD/.STL files/Door-Lower Part.STEP.STL
154.7 x 62.5 x 132.4

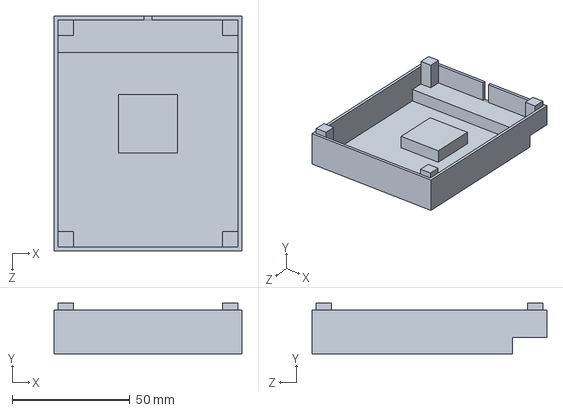
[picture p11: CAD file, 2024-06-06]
mechanical design/CAD/Solidworks files/Module casing base 2024.SLDPRT
80.0 x 21.6 x 100.0 mm

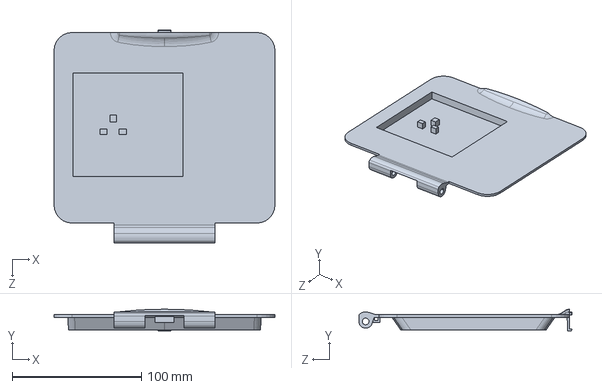
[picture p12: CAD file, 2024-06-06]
mechanical design/CAD/Solidworks files/Door top 2024.SLDPRT
171.0 x 16.7 x 165.0 mm

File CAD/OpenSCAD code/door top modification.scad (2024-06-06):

translate([-68,-77.5,-68.5]) {
    rotate([90,0,90]) {
        import("/Users/vanessalam/Desktop/Door-Lower Part.STEP.STL");
        }
    }   
//diffence() {

translate([-76.25,-85.5,-68.5]) {
    rotate([90,0,90]) {
        color([0.8,0.4,0,1]) {
            import("/Users/vanessalam/Desktop/Door-Top Part.STEP.STL");
            }
        }
    }
   
   // }
    
    

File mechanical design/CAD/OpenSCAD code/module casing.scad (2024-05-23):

//casing bottom
difference() {
    cube([22,54,6], true);   
    
    translate([0,0,0.5]) {
        cube([21.5,53.5,6], true);
        }
    }
    
//connections to pico
translate([-6,-24,-1]){
    cylinder(h = 4, r=1, center = true);
    } 
    
translate([6,-24,-1]){
    cylinder(h = 4, r=1, center = true);
    } 
    
translate([6,24,-1]){
    cylinder(h = 4, r=1, center = true);
    } 
    
translate([-6,24,-1]){
    cylinder(h = 4, r=1, center = true);
    } 
    
 

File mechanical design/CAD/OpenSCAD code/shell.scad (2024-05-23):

// bottom case (purple)
translate([-212,-176.5,-130]){
    color(c=[0.3,0,0.3,1]){
        import("/Users/vanessalam/Desktop/Hex case V2-1.STEP.STL");
        }
    }
 
// top case (blue)
rotate([0, 180,0]){   
    translate([-212,-176.5,-130]){
        color(c=[0,0.3,0.5,1]){
            import("/Users/vanessalam/Desktop/Hex case V2-1.STEP.STL");
        }
        }
    }

// bottom chassis (green)
rotate([90, 180,0]){
    translate([-131,-2,-195]){
        color(c=[0,0.5,0.3,1]){
            import("/Users/vanessalam/Desktop/Chassis S V2-1.STEP.STL");
            }
        }
    }
 
// top chassis (yellow)
rotate([90, 0,0]){
    translate([-131,-2,-195]){
        import("/Users/vanessalam/Desktop/Chassis S V2-1.STEP.STL");
        }
    }
    

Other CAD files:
mechanical design/CAD/.STL files/SMILE - shell only.STL

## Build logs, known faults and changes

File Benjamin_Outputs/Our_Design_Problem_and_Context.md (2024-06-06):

## Some additional context:
This project was taken on by a team last year, here is the progress they made and where they fell short:

- successfully made an electronic circuit that displayed the temperature and remaining cool life
- was not very modular, required removal of door which was tedious in practice.
- ambiguous in their final recommendation for position of the temperature sensor
- did not quantify the effect of the electronics module compromising insulation
- mechanical issues with door ergonomics, lack of protection for display screen

<br />

## Formalising the primary design problem:
- electronics module with temperature sensor to inform algorithm and display for user
- module should be clip on clip off (opt in design, easy charging)
- minimise compromise to insulation
- target budget: £15 (batch size ~3000)

<br />

## Our Design Process

### Default Physical Arrangement



*Why is there a 'default'? Shouldn't this be an open design problem?*

This is an open design problem, but it has a starting point. 

The starting point reflects the initial preferences of the project partner, which are informed by designs and analysis presented to her by previous contributors to this project. 

Given this, the quality of the [communication and justification of our design decisions](https://github.com/Technology-for-the-Poorest-Billion/2024-ideabatic-beam/blob/main/Benjamin_Outputs/Design_Approach.md) is crucial.

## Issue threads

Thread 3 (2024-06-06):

stl files missing?

akabla, 2024-06-06:
In the file:
door top modification.scad

there are references to:
        import("/Users/vanessalam/Desktop/Door-Lower Part.STEP.STL");
        import("/Users/vanessalam/Desktop/Door-Top Part.STEP.STL");

Where can we find these files?

nesslam, 2024-06-07:
I forgot to add them as they were part of a bigger .STL folder where only part of the folder was uploaded. I can add them now.

akabla, 2024-06-07:
That'd be great @nesslam , just to make sure there is a complete set for the partners. Thanks!

akabla, 2024-06-07:
ps: please close this issue when you've done it.

nesslam, 2024-06-07:
ok, thanks!

Closed 2024-06-07.

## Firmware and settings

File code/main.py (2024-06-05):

from time import sleep, time
from machine import Pin
from oledDisplay import *
import test
from tempSensor import tempMeasure
from buzzer import buzz
from constants import updateJson, dumpJson

class SoftSwitch():
    """Switch Class
 
    Class for defining a switch. Uses internal state to debounce switch in
    software. To use switch, check the "new_value_available" member and the
    "value" member from the application.
    
    Addition by Romeo: able to detect double clicks, if this doesn't work try
    clicking the button down, then clicking it again quickly, or adjusting the
    sensitivity in self.sensitivity.
    """
    def __init__(self, pin, constants: dict, tempMeasure, changeDisplay, checks=3, check_period=80):
        self.pin = pin
        self.pin.irq(handler=self._switch_change,
                     trigger= machine.Pin.IRQ_RISING | machine.Pin.IRQ_FALLING)
 
        self.debounce_timer = machine.Timer(-1)
        self.new_value_available = False
        self.value = pin.value
        self.prev_value = None
        self.debounce_checks = 0
        self.checks = checks
        self.check_period = check_period
        self.sensitivity = 0.35
        self.reverted = False
        self.timeFinished = False
        self.previousTime = False
        
    def endTimer(self):
        self.timeFinished = True
 
    def _switch_change(self, pin):
        self.value = pin.value
        # Start timer to check for debounce
        self.debounce_checks = 0
        self._start_debounce_timer()
 
        # Disable IRQs for GPIO pin while debouncing
        self.pin.irq(trigger=0)
 
    def _start_debounce_timer(self):
        self.debounce_timer.init(period=self.check_period, mode=machine.Timer.ONE_SHOT,
                                 callback=self._check_debounce)
 
    def _check_debounce(self, _):
        new_value = self.pin.value
 
        if new_value == self.value:
            self.debounce_checks += 1
 
            if self.debounce_checks == self.checks:
                # Values are the same, debouncing done
 
                # Check if this is actually a new value for the application
                if self.prev_value != self.value:
                    self.new_value_available = True
                    self.prev_value = self.value
                
                if self.prev_value == None:
                    started = True
                    
                    
                self.currentTime = time()
                if not self.previousTime:
                    self.previousTime = self.currentTime - 1000 #Makes sure the first click isn't a double click
                dummyQ = False
                if self.currentTime - self.previousTime < self.sensitivity: # Check for a double click with sensitivity _
                    print("Double click detected")
                    if self.reverted == False: # Makes sure it only reverts once
                        self.reverted = True 
                        print("Reverting Q to", constants["revertQ"])
                        dummyQ = max(0, constants["revertQ"]) # Makes sure that it doesn't revert the cool life to a negative number; if 0 then can be reset
                        changeDisplay(revert = True)
                    else:
                        changeDisplay(reset = True)
                        dummyQ = constants["Qtotal"]  
                if dummyQ:     
                    global Qleft
                    Qleft = dummyQ
                    temp = tempMeasure()
                    heatLossRate = (temp) / constants["Rth"]
                    timeRemaining = dummyQ / (heatLossRate * (60*60))
                    displayTime(timeRemaining, None)
                self.previousTime = self.currentTime

 
                # Re-enable the Switch IRQ to get the next change
                self.pin.irq(handler=self._switch_change,
                             trigger = machine.Pin.IRQ_RISING | machine.Pin.IRQ_FALLING)
            else:
                # Start the timer over to make sure debounce value stays the same
                self._start_debounce_timer()
        else:
            # Values are not the same, update value we're checking for and
            # delay again
            self.debounce_checks = 0
            self.value = new_value
            self._start_debounce_timer()

#initialise extra components
buzzer = Pin(10, Pin.OUT, Pin.PULL_DOWN) # Buzzer is connected between GPIO pin 14 (board pin 19), and ground. Polarity does matter
pushButton = Pin(18, Pin.IN, Pin.PULL_UP) # Push button is connected between GPIO pin 15 (board pin 20) and ground)
doorSwitch = Pin(14, Pin.IN, Pin.PULL_UP) # Door switch is connected between GPIO pin 16 (board pin 21), and ground
constants = updateJson('constants.json') # Import all the relevant constants
Qleft = constants["Qtotal"] # Initialises heat energy.
endBuzz = False

def wait_for_start(x):
    """
    An interrupt raised at the start, caused by the push button.
    This commences the rest of the code.
    """
    pushButton.irq(trigger=0) # Disable the interrupt to prevent further recursions
    global started
    started = True
    return

#try:
pushButton.irq(trigger=Pin.IRQ_RISING, handler=wait_for_start) # Attach the interrupt to the push button
print("Waiting to start; push the button or insert the module to start the timer")
# Waits for the button to be pushed to start the programme
started = False
waitForStart()
while started is False:
    sleep(1)
    continue
print("starting")
pushButton = SoftSwitch(Pin(18, machine.Pin.IN, machine.Pin.PULL_UP), constants, tempMeasure, changeDisplay) # THIS REQUIRES A TECHNICAL PRESS, PUSH THE BUTTON THEN PUSH AGAIN IN QUICK SUCCESSION, OR A QUICK TRIPLE CLICK
count = 0 # A counter for the number of loops the door has been left open
lastTime = time()
while True:
    timeDiff = (time() - lastTime) # Used to calculate the time difference over which heat was lost
    temp = tempMeasure()
    heatLossRate = (temp) / constants["Rth"] # (W), note the temp is actually a temperature difference, but since the ice pack core is 0C, the temperature in Celcius alone works
    QLoss = heatLossRate * (timeDiff) # (Heat energy, J, lost to surroundings).
    Qleft -= QLoss #Calculate remaining Q
    if Qleft <=0:
        pushButton.endTimer()
        if endBuzz == False:
            buzz(buzzer, 2)
            endBuzz = True
    timeRemaining = Qleft / (heatLossRate * (60*60)) # in hours
    print(timeRemaining) # For testing, note that at 1s intervals, approx time loss in hrs is 0.00028 (at constant T)
    displayTime(timeRemaining, False)                                                                         
    lastTime = time()
    currentSwitch = doorSwitch.value()
    if currentSwitch == 1: # Checks if the door is open. Waits another iteration: if the door is still open, buzz
        count+=1
        if count >=2:
            #count = 0
            buzz(buzzer, 1)
    else:
        count = 0
    sleep(constants["tdelta"]) # Polling rate of tdelta, default 5 mins
    
#except:
print("Error raised somewhere / KBDInterrupt.")
turnoff()
constants["revertQ"] = Qleft
constants["revertTime"] = time()
dumpJson("constants.json", constants)

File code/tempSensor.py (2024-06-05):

from machine import Pin
from time import sleep
from dht import DHT22
# Initialising GPIO und DHT22
dht22_sensor = DHT22(Pin(5, Pin.IN, Pin.PULL_UP))

def tempMeasure():
    """
    Communicates with DHT22 chip and returns the temperature
    """
    dht22_sensor.measure()
    temp = dht22_sensor.temperature()
    return temp

def tempLoop():
    """
    Simple loop for testing; returns the temperature and humidity readings from the DHT22 chip.
    """
    i=0
    while True:
        sleep(2)
        i+=1
        dht22_sensor.measure()
        temp, humi = dht22_sensor.temperature(), dht22_sensor.humidity()
        print('Reading {}, Temperature: {:0.1f}C, Humidity: {:0.1f}%'.format(i, temp, humi))


#Uncomment the below to get temperature values.
        
#tempLoop()

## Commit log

2024-05-16 Update management.md
    Minor, added connectors and battery context, commented out prompts.
2024-05-20 Create Contents for CAD files
2024-05-23 preliminary design for module casing
    [module casing.scad]
2024-05-23 make .STL files compatible with openScad
    [shell.scad]
2024-06-03 Code for pico
    Should be entirely functional.
2024-06-06 Rename CAD/module casing.scad to CAD/OpenSCAD code/module casing.scad
    [module casing.scad]
2024-06-06 Rename CAD/shell.scad to CAD/OpenSCAD code/shell.scad
    [shell.scad]
2024-06-06 Rename CAD/Door top 2024.SLDPRT to CAD/Solidwork files/Door top 2024.SLDPRT
    [Door top 2024.SLDPRT]
2024-06-06 Rename CAD/Module casing base 2024.SLDPRT to CAD/Solidwork files/Module casing base 2024.SLDPRT
    [Module casing base 2024.SLDPRT]
2024-06-06 Rename CAD/Module casing top 2024.SLDPRT to CAD/Solidworks files/Module casing top 2024.SLDPRT
    [Module casing top 2024.SLDPRT]
2024-06-06 Rename CAD/Solidwork files/Door top 2024.SLDPRT to CAD/Solidworks files/Door top 2024.SLDPRT
    [Solidworks filesDoor top 2024.SLDPRT]
2024-06-06 Rename CAD/Solidworks filesDoor top 2024.SLDPRT to CAD/Solidworks files/Door top 2024.SLDPRT
    [Door top 2024.SLDPRT]
2024-06-06 Rename Module casing base 2024.SLDPRT to Module casing base 2024.SLDPRT
    [Module casing base 2024.SLDPRT]
2024-06-06 Rename door top modification to door top modification.scad
    [door top modification.scad]
2024-06-06 Rename CAD/OpenSCAD code/door top modification.scad to mechanical design/CAD/OpenSCAD code/door top modification.scad
    [door top modification.scad]
2024-06-06 Rename mechanical design/CAD/OpenSCAD code/door top modification.scad to CAD/OpenSCAD code/door top modification.scad
    [door top modification.scad]
2024-06-06 Rename CAD/OpenSCAD code/module casing.scad to mechanical design/CAD/OpenSCAD code/module casing.scad
    [module casing.scad]
2024-06-06 Rename CAD/OpenSCAD code/shell.scad to mechanical design/CAD/OpenSCAD code/shell.scad
    [shell.scad]
2024-06-06 Rename CAD/Solidworks files/Door top 2024.SLDPRT to mechanical design/CAD/Solidworks files/Door top 2024.SLDPRT
    [Door top 2024.SLDPRT]
2024-06-06 Rename CAD/Solidworks files/Module casing base 2024.SLDPRT to mechanical design/CAD/Solidworks files/Module casing base 2024.SLDPRT
    [Module casing base 2024.SLDPRT]
2024-06-06 Rename CAD/Solidworks files/Module casing top 2024.SLDPRT to mechanical design/CAD/Solidworks files/Module casing top 2024.SLDPRT
    [Module casing top 2024.SLDPRT]
2024-06-06 Rename CAD/SMILE - shell only.STL to mechanical design/CAD/SMILE - shell only.STL
    [SMILE - shell only.STL]
2024-06-06 Create drop resistance.md
2024-06-06 Update drop resistance.md
2024-06-06 Create Final product material design
2024-06-06 Rename Final product material design to final product material.md
2024-06-07 Update and rename mechanical design/CAD/SMILE - shell only.STL to mechanical design/CAD/.STL files/SMILE - shell only.STL
    [SMILE - shell only.STL]
